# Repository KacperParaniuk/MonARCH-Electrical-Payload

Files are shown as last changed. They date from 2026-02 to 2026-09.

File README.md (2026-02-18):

# MonARCH Payload Interface Board

## Getting started

To make it easy for you to get started with GitLab, here's a list of recommended next steps.

Already a pro? Just edit this README.md and make it your own. Want to make it easy? [Use the template at the bottom](#editing-this-readme)!

## Add your files

- [ ] [Create](https://docs.gitlab.com/ee/user/project/repository/web_editor.html#create-a-file) or [upload](https://docs.gitlab.com/ee/user/project/repository/web_editor.html#upload-a-file) files
- [ ] [Add files using the command line](https://docs.gitlab.com/topics/git/add_files/#add-files-to-a-git-repository) or push an existing Git repository with the following command:

```
cd existing_repo
git remote add origin https://gitlab.engr.illinois.edu/cubesat/monarch-payload-interface-board.git
git branch -M main
git push -uf origin main
```

## Integrate with your tools

- [ ] [Set up project integrations](https://gitlab.engr.illinois.edu/cubesat/monarch-payload-interface-board/-/settings/integrations)

## Collaborate with your team

- [ ] [Invite team members and collaborators](https://docs.gitlab.com/ee/user/project/members/)
- [ ] [Create a new merge request](https://docs.gitlab.com/ee/user/project/merge_requests/creating_merge_requests.html)
- [ ] [Automatically close issues from merge requests](https://docs.gitlab.com/ee/user/project/issues/managing_issues.html#closing-issues-automatically)
- [ ] [Enable merge request approvals](https://docs.gitlab.com/ee/user/project/merge_requests/approvals/)
- [ ] [Set auto-merge](https://docs.gitlab.com/user/project/merge_requests/auto_merge/)

## Test and Deploy

Use the built-in continuous integration in GitLab.

- [ ] [Get started with GitLab CI/CD](https://docs.gitlab.com/ee/ci/quick_start/)
- [ ] [Analyze your code for known vulnerabilities with Static Application Security Testing (SAST)](https://docs.gitlab.com/ee/user/application_security/sast/)
- [ ] [Deploy to Kubernetes, Amazon EC2, or Amazon ECS using Auto Deploy](https://docs.gitlab.com/ee/topics/autodevops/requirements.html)
- [ ] [Use pull-based deployments for improved Kubernetes management](https://docs.gitlab.com/ee/user/clusters/agent/)
- [ ] [Set up protected environments](https://docs.gitlab.com/ee/ci/environments/protected_environments.html)

***

# Editing this README

When you're ready to make this README your own, just edit this file and use the handy template below (or feel free to structure it however you want - this is just a starting point!). Thanks to [makeareadme.com](https://www.makeareadme.com/) for this template.

## Suggestions for a good README

Every project is different, so consider which of these sections apply to yours. The sections used in the template are suggestions for most open source projects. Also keep in mind that while a README can be too long and detailed, too long is better than too short. If you think your README is too long, consider utilizing another form of documentation rather than cutting out information.

## Name
Choose a self-explaining name for your project.

## Description
Let people know what your project can do specifically. Provide context and add a link to any reference visitors might be unfamiliar with. A list of Features or a Background subsection can also be added here. If there are alternatives to your project, this is a good place to list differentiating factors.

## Badges
On some READMEs, you may see small images that convey metadata, such as whether or not all the tests are passing for the project. You can use Shields to add some to your README. Many services also have instructions for adding a badge.

## Visuals
Depending on what you are making, it can be a good idea to include screenshots or even a video (you'll frequently see GIFs rather than actual videos). Tools like ttygif can help, but check out Asciinema for a more sophisticated method.

## Installation
Within a particular ecosystem, there may be a common way of installing things, such as using Yarn, NuGet, or Homebrew. However, consider the possibility that whoever is reading your README is a novice and would like more guidance. Listing specific steps helps remove ambiguity and gets people to using your project as quickly as possible. If it only runs in a specific context like a particular programming language version or operating system or has dependencies that have to be installed manually, also add a Requirements subsection.

## Usage
Use examples liberally, and show the expected output if you can. It's helpful to have inline the smallest example of usage that you can demonstrate, while providing links to more sophisticated examples if they are too long to reasonably include in the README.

## Support
Tell people where they can go to for help. It can be any combination of an issue tracker, a chat room, an email address, etc.

## Roadmap
If you have ideas for releases in the future, it is a good idea to list them in the README.

## Contributing
State if you are open to contributions and what your requirements are for accepting them.

For people who want to make changes to your project, it's helpful to have some documentation on how to get started. Perhaps there is a script that they should run or some environment variables that they need to set. Make these steps explicit. These instructions could also be useful to your future self.

You can also document commands to lint the code or run tests. These steps help to ensure high code quality and reduce the likelihood that the changes inadvertently break something. Having instructions for running tests is especially helpful if it requires external setup, such as starting a Selenium server for testing in a browser.

## Authors and acknowledgment
Show your appreciation to those who have contributed to the project.

## License
For open source projects, say how it is licensed.

## Project status
If you have run out of energy or time for your project, put a note at the top of the README saying that development has slowed down or stopped completely. Someone may choose to fork your project or volunteer to step in as a maintainer or owner, allowing your project to keep going. You can also make an explicit request for maintainers.

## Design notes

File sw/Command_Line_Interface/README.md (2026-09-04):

# MonARCH Payload Interface Board Command Line Interface

*Created By Kacper Paraniuk 07-09-26 

[Dependency Info](#dependency-info)

[How to Set Up Dependencies](#how-to-set-up-dependencies--run-monarch-cli)

[1. UV INSTALLATION](#1-uv-installation-httpsdocsastralshuvgetting-startedinstallation)

[2. PYTHON](#2-python-httpsdocsastralshuvguidesinstall-python)

[3. RUNNING SCRIPT](#3-running-the-code)

[4. COMMANDING THE PIB](#4-commanding-the-pib)

[Common Errors](#common-errors)

## Dependency Info 

This markdown file discusses the structure of the payload interface shell (command line interface) and how to set it up 

uv — project + dependency management (replaces pip/venv juggling)

UV 

cmd module || read more here: https://docs.python.org/3/library/cmd.html

pyserial — external dependency for the serial side

cmd (Python stdlib, no install needed) — gives nice terminal commanding functionality  

## HOW TO SET UP DEPENDENCIES & RUN MonARCH CLI:

- type in terminal inside of project directory and run >

*If you do have UV installed:

uv sync (Make sure this is correct)

*If you do not have UV installed: 

### 1. UV INSTALLATION (https://docs.astral.sh/uv/getting-started/installation/)

WINDOWS - 

powershell -ExecutionPolicy ByPass -c "irm https://astral.sh/uv/install.ps1 | iex"

MAC - 

curl -LsSf https://astral.sh/uv/install.sh | sh

RESTART TERMINAL TO ADD UV TO PATH 

### 2. PYTHON (https://docs.astral.sh/uv/guides/install-python/)

If you do not have python no worries UV can manage your python type

uv python install

If you have python skip this step. 

### 3. RUNNING THE CODE

cd pib-cli # make sure you are in the pib-cli folder

uv run python main.py (port default = 12 | baud rate default = 115200) 

OR

uv run python main.py --port {Input COMX} --baud {Input Baud Rate}

Allows the user to specify the serial port and baud rate for the Arduino connection.

Windows: 

List COM ports with:

mode 

PS C:\dev\monarch-payload-interface-board\sw\Command_Line_Interface> mode

Status for device COM12:
------------------------
    Baud:            0
    Parity:          None
    Data Bits:       0
    Stop Bits:       1
    Timeout:         OFF
    XON/XOFF:        OFF
    CTS handshaking: OFF
    DSR handshaking: OFF
    DSR sensitivity: OFF
    DTR circuit:     OFF
    RTS circuit:     ON

Status for device CON:
----------------------
    Lines:          30
    Columns:        120
    Keyboard rate:  31
    Keyboard delay: 1
    Code page:      437

as you can see COM12 is active. 

then 

uv run python main.py --port COM12

MAC: 

List COM ports with 

ls /dev/cu.*

and the following should show up  
kacper@Kacpers-MacBook-Air-4 MonARCH-Payload-Control % ls /dev/cu.*
/dev/cu.BeatsFitPro             /dev/cu.debug-console           /dev/cu.usbmodem11101
/dev/cu.Bluetooth-Incoming-Port /dev/cu.HC-05                   /dev/cu.wlan-debug

then run the following command inside of pib-cli directory 

uv run python main.py --port /dev/cu.usbmodem11101

 1
### 4. Commanding the PIB!

If you sucessfully executed the program then you should see the following message:
    "Welcome to the PIB shell. Use with an arduino to command the payload interface board of MonARCH. Type help or ? to list commands."

Now you can start running various commands.

See the command .md [Commanding the PIB](https://github.com/KacperParaniuk/MonARCH-Payload-Control/blob/main/Command_Line_Interface/cmds.md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)

# Common Errors: 

 >   raise SerialException(msg.errno, "could not open port {}: {}".format(self._port, msg))

This is due to the python script failing a handshake with the arduino board. Please check the connection between computer and arduino board. Also check if you are specifiying the correct port the device is identified at.

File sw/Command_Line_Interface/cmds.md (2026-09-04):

Created By Kacper Paraniuk 07-06-26 

This is a markdown file containing the commands for cli of the payload interface board 

[Command Structure](#command-structure)

[Commands Explanation](#commands-explanation)

[Commands](#commands)

# Command Structure

The command structure is:

 <verb> <target> 

# Commands Explanation: 

Sensors 
-----------------------------------------------------------------------------------------------------------

<verb> <target> <[num]>

ex: 

read_cj_temp 1 

read_pressure 2

read_temp 5

Actions 
-----------------------------------------------------------------------------------------------------------
<verb> <target> <[num]>

ex: 

open_valve 3

toggle_red_led

Events -----------------------------------------------------------------------------------------------------------

<verb> <event>

ex: 

run_sequence fill_accum1

run_sequence run_espray 

# PIB Shell Commands

| Command | Usage | Description |
|---|---|---|
| `greet` | `greet <text>` | Echoes back `Hello <text>` |
| `exit` | `exit` | Echoes `Exiting the PIB shell.` and exits the script |
| `help` | `help` | Returns a list of commands
| `toggle_red_led` | `toggle_red_led` | Toggles the red debug LED on the PIB |
| `open_valve` | `open_valve <valve #>` | Opens the specified valve |
| `close_valve` | `close_valve <valve #>` | Closes the specified valve |
| `read_cj_temp` | `read_cj_temp <sensor #>` | Returns the cold junction temperature |
| `

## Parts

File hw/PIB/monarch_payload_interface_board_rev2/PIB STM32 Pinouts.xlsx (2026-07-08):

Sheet: Pinout Descriptions
Model | STM32L4A6VGT6 |  |  |  |  | Legend
Package | 100 - LQFP |  |  |  |  | Name | Abbreviation | Definition
 |  |  |  |  |  | Pin name | Unless otherwise specified in brackets below the pin name, the pin function during and after reset is the same as the actual pin name
 |  |  |  |  |  | Pin type | S | Supply pin
Pin Number | Pin Name | Pin Type | I/O Structure | Function | Description |  | I | Input only pin
1 | PE2 | I/O | FT_l | GPIO | Chip Select for Thermocouple 4 |  | I/O | Input / output pin
2 | PE3 | I/O | FT_l | GPIO | Chip Select for Thermocouple 2 | I/O structure | FT | 5 V tolerant I/O
3 | PE4 | I/O | FT | GPIO | Chip Select for Pressure Transducer ADC |  | TT | 3.6 V tolerant I/O
4 | PE5 | I/O | FT | TIM3_CH3 | Advanced Clock for Controlling Valve6 |  | RST | Bidirectional reset pin with embedded weak pull-up resistor
5 | PE6 | I/O | FT | N/A | Not Connected |  | Option for TT or FT I/Os
6 | VBAT | S | - | N/A | Not Connected |  | _f | I/O, Fm+ capable
7 | PC13 | I/O | FT | N/A | Not Connected |  | _l | I/O, with LCD function supplied by VLCD
8 | PC14 | I/O | FT | N/A | Not Connected |  | _u | I/O, with USB function supplied by VDDUSB
9 | PC15 | I/O | FT | N/A | Not Connected |  | _a | I/O, with Analog switch function supplied by VDDA
10 | VSS | S | - | GND | Ground Pin |  | _s | I/O supplied only by VDDIO2
11 | VDD | S | - | 3V3 | 3V3 Supply Pin | Color Coding |  | Pin Not Connected
12 | PH0 | I/O | FT | GPIO | Enable Pin for DC/DC Converter |  |  | GPIO for Controlling Valves / Chip Selects
13 | PH1 | I/O | FT | N/A | Not Connected |  |  | Ground Pins
14 | NRST | I/O | RST | RST | Reset Pin |  |  | 3V3 Supply Pins
15 | PC0 | I/O | FT_fla | N/A | Not Connected |  |  | Reset Pin
16 | PC1 | I/O | FT_fla | N/A | Not Connected |  |  | Communication Protocols
17 | PC2 | I/O | FT_la | N/A | Not Connected |  |  | Advanced Timers for Valves 4 & 6
18 | PC3 | I/O | FT_la | N/A | Not Connected |  |  | STLink Pins for Programming Pin Headers
19 | VSSA | S | - | GND | Analog Ground Pin (Same as GND)
20 | VREF- | S | - | GND | Reference Ground Pin (Same as GND)
21 | VREF+ | S | - | 3V3 | Reference Voltage Pin (Same as 3V3)
22 | VDDA | S | - | 3V3 | Analog Voltage Pin (Same as 3V3)
23 | PA0 | I/O | FT_a | UART4_TX | UART Protocol for PPU Communication
24 | PA1 | I/O | FT_la | UART4_RX | UART Protocol for PPU Communication
25 | PA2 | I/O | FT_la | N/A | Not Connected
26 | PA3 | I/O | TT_la | N/A | Not Connected
27 | VSS | S | - | GND | Ground Pin
28 | VDD | S | - | 3V3 | 3V3 Supply Pin
29 | PA4 | I/O | TT_a | GPIO | Chip Select for Current Measurement ADC
30 | PA5 | I/O | TT_a | SPI1_SCK | SPI Clock for ADC
31 | PA6 | I/O | FT_la | SPI1_MISO | SPI MISO for ADC
32 | PA7 | I/O | FT_fla | SPI1_MOSI | SPI MOSI for ADC
33 | PC4 | I/O | FT_la | USART3_TX | USART Protocol for OBC Communication
34 | PC5 | I/O | FT_la | USART3_RX | USART Protocol for OBC Communication
35 | PB0 | I/O | TT_la | N/A | Not Connected
36 | PB1 | I/O | FT_la | N/A | Not Connected
37 | PB2 | I/O | FT_la | N/A | Not Connected
38 | PE7 | I/O | FT | N/A | Not Connected
39 | PE8 | I/O | FT | N/A | Not Connected
40 | PE9 | I/O | FT | N/A | Not Connected
41 | PE10 | I/O | FT | N/A | Not Connected
42 | PE11 | I/O | FT | N/A | Not Connected
43 | PE12 | I/O | FT | N/A | Not Connected
44 | PE13 | I/O | FT | GPIO | GPIO for Test LED (BLUE)
45 | PE14 | I/O | FT | GPIO | GPIO for Test LED (GREEN)
46 | PE15 | I/O | FT | GPIO | GPIO for Test LED (RED)
47 | PB10 | I/O | FT_fl | I2C4_SCL | I2C Protocol for Breakout Board Communication
48 | PB11 | I/O | FT_fl | I2C4_SDA | I2C Protocol for Breakout Board Communication
49 | VSS | S | - | GND | Ground Pin
50 | VDD | S | - | 3V3 | 3V3 Supply Pin
51 | PB12 | I/O | FT_l | GPIO | GPIO for Valve1
52 | PB13 | I/O | FT_fl | GPIO | GPIO for Valve2
53 | PB14 | I/O | FT_fl | GPIO | GPIO for Valve3
54 | PB15 | I/O | FT_l | GPIO | GPIO for Valve5
55 | PD8 | I/O | FT_l | GPIO | GPIO for Valve7
56 | PD9 | I/O | FT_l | GPIO | GPIO for Valve8
57 | PD10 | I/O | FT_l | N/A | Not Connected
58 | PD11 | I/O | FT_l | N/A | Not Connected
59 | PD12 | I/O | FT_fl | N/A | Not Connected
60 | PD13 | I/O | FT_fl | N/A | Not Connected
61 | PD14 | I/O | FT_l | N/A | Not Connected
62 | PD15 | I/O | FT_l | N/A | Not Connected
63 | PC6 | I/O | FT_l | TIM8_CH1 | Advanced Clock for Controlling Valve4
64 | PC7 | I/O | FT_l | GPIO | GPIO for Valve9
65 | PC8 | I/O | FT_l | GPIO | GPIO for Valve10
66 | PC9 | I/O | FT_fl | GPIO | GPIO for Valve11
67 | PA8 | I/O | FT_l | GPIO | GPIO for Valve12
68 | PA9 | I/O | FT_lu | N/A | Not Connected
69 | PA10 | I/O | FT_lu | GPIO | GPIO for Heater0
70 | PA11 | I/O | FT_u | GPIO | GPIO for Valve18
71 | PA12 | I/O | FT_u | N/A | Not Connected
72 | PA13 (JTMS / SWDIO) | I/O | FT | JTMS | JTMS for STLink Programming
73 | VDDUSB | S | - | N/A | Not Connected
74 | VSS | S | - | GND | Ground Pin
75 | VDD | S | - | 3V3 | 3V3 Supply Pin
76 | PA14 (JTCK / SWCLK) | I/O | FT | JTCK | JTCK for STLink Programming
77 | PA15 (JTDI) | I/O | FT_l | JTDI | JTDI for STLink Programming
78 | PC10 | I/O | FT_l | GPIO | GPIO for Value13
79 | PC11 | I/O | FT_l | GPIO | GPIO for Valve14
80 | PC12 | I/O | FT_l | GPIO | GPIO for Valve16
81 | PD0 | I/O | FT | GPIO | GPIO for Valve17
82 | PD1 | I/O | FT | SPI2_SCK | SPI_SCK for Thermocouple Chips
83 | PD2 | I/O | FT_l | GPIO | GPIO for Valve15
84 | PD3 | I/O | FT | SPI2_MISO | SPI_MISO for Thermocouple Chips
85 | PD4 | I/O | FT | SPI2_MOSI | SPI_MOSI for Termocouple Chips
86 | PD5 | I/O | FT | N/A | Not Connected
87 | PD6 | I/O | FT | N/A | Not Connected
88 | PD7 | I/O | FT | N/A | Not Connected
89 | PB3 (JTDO / TRACES WO) | I/O | FT_la | JTDO | JTDO for STLink Programming
90 | PB4 (NJTRST) | I/O | FT_fla | NJTRST | NJTRST for STLink Programming
91 | PB5 | I/O | FT_la | N/A | Not Connected
92 | PB6 | I/O | FT_fa | N/A | Not Connected
93 | PB7 | I/O | FT_fla | N/A | Not Connected
94 | PH3-BOOT0 | I/O | FT | N/A | Not Connected
95 | PB8 | I/O | FT_fl | N/A | Not Connected
96 | PB9 | I/O | FT_fl | GPIO | Chip Select for Thermocouple 1
97 | PE0 | I/O | FT_l | GPIO | Chip Select for Thermocouple 3
98 | PE1 | I/O | FT_l | GPIO | Chip Select for Thermocouple 5
99 | VSS | S | - | GND | Ground Pin
100 | VDD | S | - | 3V3 | 3V3 Supply Pin

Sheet: STM Model
 |  | 25 | 24 | 23 | 22 | 21 | 20 | 19 | 18 | 17 | 16 | 15 | 14 | 13 | 12 | 11 | 10 | 9 | 8 | 7 | 6 | 5 | 4 | 3 | 2 | 1
 |  | NC | UART4_TX | UART4_RX | 3V3 | 3V3 | GND | GND | NC | NC | NC | NC | NRST | NC | EN | 3V3 | GND | NC | NC | NC | NC | NC | NC | PT | T2 | T4
26 | NC | STM32 |  |  |  |  |  |  |  |  |  |  |  |  |  |  |  |  |  |  |  |  |  |  |  |  | 3V3 | 100
27 | GND |  |  |  |  |  |  |  |  |  |  |  |  |  |  |  |  |  |  |  |  |  |  |  |  |  | GND | 99
28 | 3V3 |  |  |  |  |  |  |  |  |  |  |  |  |  |  |  |  |  |  |  |  |  |  |  |  |  | T5 | 98
29 | ADC |  |  |  |  |  |  |  |  |  |  |  |  |  |  |  |  |  |  |  |  |  |  |  |  |  | T3 | 97
30 | SPI1_SCK |  |  |  |  |  |  |  |  |  |  |  |  |  |  |  |  |  |  |  |  |  |  |  |  |  | T1 | 96
31 | SPI1_MISO |  |  |  |  |  |  |  |  |  |  |  |  |  |  |  |  |  |  |  |  |  |  |  |  |  | NC | 95
32 | SPI1_MOSI |  |  |  |  |  |  |  |  |  |  |  |  |  |  |  |  |  |  |  |  |  |  |  |  |  | NC | 94
33 | USART3_TX |  |  |  |  |  |  |  |  |  |  |  |  |  |  |  |  |  |  |  |  |  |  |  |  |  | NC | 93
34 | USART3_RX |  |  |  |  |  |  |  |  |  |  |  |  |  |  |  |  |  |  |  |  |  |  |  |  |  | NC | 92
35 | NC |  |  |  |  |  |  |  |  |  |  |  |  |  |  |  |  |  |  |  |  |  |  |  |  |  | NC | 91
36 | NC |  |  |  |  |  |  |  |  |  |  |  |  |  |  |  |  |  |  |  |  |  |  |  |  |  | NJTRST | 90
37 | NC |  |  |  |  |  |  |  |  |  |  |  |  |  |  |  |  |  |  |  |  |  |  |  |  |  | JTDO | 89
38 | NC |  |  |  |  |  |  |  |  |  |  |  |  |  |  |  |  |  |  |  |  |  |  |  |  |  | NC | 88
39 | NC |  |  |  |  |  |  |  |  |  |  |  |  |  |  |  |  |  |  |  |  |  |  |  |  |  | NC | 87
40 | Valve6 |  |  |  |  |  |  |  |  |  |  |  |  |  |  |  |  |  |  |  |  |  |  |  |  |  | NC | 86
41 | NC |  |  |  |  |  |  |  |  |  |  |  |  |  |  |  |  |  |  |  |  |  |  |  |  |  | SPI2_MOSI | 85
42 | NC |  |  |  |  |  |  |  |  |  |  |  |  |  |  |  |  |  |  |  |  |  |  |  |  |  | SPI2_MISO | 84
43 | NC |  |  |  |  |  |  |  |  |  |  |  |  |  |  |  |  |  |  |  |  |  |  |  |  |  | Valve15 | 83
44 | NC |  |  |  |  |  |  |  |  |  |  |  |  |  |  |  |  |  |  |  |  |  |  |  |  |  | SPI2_SCK | 82
45 | NC |  |  |  |  |  |  |  |  |  |  |  |  |  |  |  |  |  |  |  |  |  |  |  |  |  | Valve17 | 81
46 | LED |  |  |  |  |  |  |  |  |  |  |  |  |  |  |  |  |  |  |  |  |  |  |  |  |  | Valve16 | 80
47 | I2C4_SCL |  |  |  |  |  |  |  |  |  |  |  |  |  |  |  |  |  |  |  |  |  |  |  |  |  | Valve14 | 79
48 | I2C4_SDA |  |  |  |  |  |  |  |  |  |  |  |  |  |  |  |  |  |  |  |  |  |  |  |  |  | Valve13 | 78
49 | GND |  |  |  |  |  |  |  |  |  |  |  |  |  |  |  |  |  |  |  |  |  |  |  |  |  | JTDI | 77
50 | 3V3 |  |  |  |  |  |  |  |  |  |  |  |  |  |  |  |  |  |  |  |  |  |  |  |  |  | JTCK | 76
 |  | Valve1 | Valve2 | Valve3 | Valve5 | Valve7 | Valve8 | NC | NC | NC | NC | NC | NC | Valve4 | Valve9 | Valve10 | Valve11 | Valve12 | NC | Heater0 | Valve18 | NC | JTMS | NC | GND | 3V3
 |  | 51 | 52 | 53 | 54 | 55 | 56 | 57 | 58 | 59 | 60 | 61 | 62 | 63 | 64 | 65 | 66 | 67 | 68 | 69 | 70 | 71 | 72 | 73 | 74 | 75

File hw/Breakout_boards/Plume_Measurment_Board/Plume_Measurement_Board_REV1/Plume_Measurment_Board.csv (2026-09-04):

Reference | Qty | Value | DNP | Exclude from BOM | Exclude from Board | Footprint | Datasheet
C1 | 1 | 620pF |  |  |  | Capacitor_SMD:C_0402_1005Metric_Pad0.74x0.62mm_HandSolder | https://www.digikey.com/en/products/detail/murata-electronics/GRM1555C1E621JA01D/2543753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
C2,C12,C14,C32,C42 | 5 | 10uF |  |  |  | Capacitor_SMD:C_0805_2012Metric_Pad1.18x1.45mm_HandSolder | https://www.digikey.com/en/products/detail/nextgen-components/0805W106K250CC/18676983
C3 | 1 | 22uF |  |  |  | Capacitor_SMD:C_0805_2012Metric_Pad1.18x1.45mm_HandSolder | https://www.digikey.com/en/products/detail/nextgen-components/0805W226M100CC/22671955
C4,C31 | 2 | .1uF |  |  |  | Capacitor_SMD:C_0603_1608Metric_Pad1.08x0.95mm_HandSolder
C5,C6,C9,C10,C38,C39,C40,C41 | 8 | 270pF |  |  |  | Capacitor_SMD:C_0603_1608Metric_Pad1.08x0.95mm_HandSolder
C7,C8,C35,C36 | 4 | 680pF |  |  |  | Capacitor_SMD:C_0603_1608Metric_Pad1.08x0.95mm_HandSolder
C11,C19,C20,C22,C25,C27,C29,C34 | 8 | 1uF |  |  |  | Capacitor_SMD:C_0603_1608Metric_Pad1.08x0.95mm_HandSolder
C13,C15,C33,C43 | 4 | 100nF |  |  |  | Capacitor_SMD:C_0603_1608Metric_Pad1.08x0.95mm_HandSolder
C16,C18,C21,C23,C26,C28,C30,C37 | 8 | 1uF |  |  |  | Capacitor_SMD:C_0805_2012Metric_Pad1.18x1.45mm_HandSolder
C17,C24 | 2 | .1pF |  |  |  | Capacitor_SMD:C_0402_1005Metric_Pad0.74x0.62mm_HandSolder | https://www.digikey.com/en/products/detail/murata-electronics/GJM1555C1HR10WB01D/2593239
J2,J4 | 2 | Conn_01x04 |  |  |  | Connector_Molex_Micro-Lock-Plus:Molex_Micro-Lock_2200980471_1x04_P1.25mm_Horizontal
J3,J5 | 2 | Conn_Coaxial |  |  |  | Connector_Coaxial:SMA_Molex_73251-2120_EdgeMount_Horizontal | https://www.digikey.com/en/products/detail/molex/0732512120/1465158?s=N4IgTCBcDaIAQHYDMYCsBGAtGdYAMcIAugL5A
L1 | 1 | 2.2uH |  |  |  | Inductor_TDK:IND_VLS3012CX-2R2M-1 | https://www.digikey.com/en/products/detail/tdk/VLS3012CX-2R2M-1/9607846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
R1 | 1 | 100k |  |  |  | Resistor_SMD:R_01005_0402Metric_Pad0.57x0.30mm_HandSolder | https://www.digikey.com/en/products/detail/vishay-dale/CRCW0402100KFKED/1178235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
R3,R4,R5,R6,R7,R8,R19,R20 | 8 | 10 |  |  |  | Resistor_SMD:R_0603_1608Metric_Pad0.98x0.95mm_HandSolder
R9,R10,R17,R18 | 4 | 1000 |  |  |  | Resistor_SMD:R_0603_1608Metric_Pad0.98x0.95mm_HandSolder
R11,R12,R15,R16 | 4 | 1000 | DNP |  |  | Resistor_SMD:R_0603_1608Metric_Pad0.98x0.95mm_HandSolder
R13,R14 | 2 | 1G |  |  |  | Resistor_SMD:R_2512_6332Metric_Pad1.40x3.35mm_HandSolder | https://www.digikey.com/en/products/detail/stackpole-electronics-inc/HVCB2512FKC1G00/1948075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
U2,U10 | 2 | LMP7721MA/NOPB |  |  |  | Amplifier_Texas_Instruments:M08A | https://www.ti.com/lit/gpn/lmp7721
U3,U11 | 2 | LMP2022MA/NOPB |  |  |  | Amplifier_Texas_Instruments:M08A | https://www.ti.com/lit/gpn/lmp2022
U4,U5,U8,U9 | 4 | AD8475ARMZ |  |  |  | Buffer_Analog_Devices:RM_10_ADI | https://www.analog.com/media/en/technical-documentation/data-sheets/AD8475.pdf
U6 | 1 | TPS62153 |  |  |  | Package_DFN_QFN:VQFN-16-1EP_3x3mm_P0.5mm_EP1.68x1.68mm_ThermalVias | http://www.ti.com/lit/ds/symlink/TPS62150.pdf
U7,U12 | 2 | AD7176-2BRUZ |  |  |  | ADC_Analog_Devices:RU_24_ADI | https://www.analog.com/media/en/technical-documentation/data-sheets/AD7176-2.pdf

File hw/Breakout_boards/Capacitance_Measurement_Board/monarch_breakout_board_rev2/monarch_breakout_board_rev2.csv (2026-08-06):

Reference | Qty | Value | DNP | Exclude from BOM | Exclude from Board | Footprint | Datasheet
U1 | 1 | FDC2214RGHR |  |  |  | FDC2214:RGH0016A | https://www.ti.com/lit/gpn/fdc2214
J9 | 1 | 2200980471 |  |  |  | Connector_Molex_Micro-Lock-Plus:Molex_Micro-Lock_2200980471_1x04_P1.25mm_Horizontal | https://www.molex.com/en-us/products/part-detail/2200980471
R1 | 1 | 100 |  |  |  | Resistor_SMD:R_0603_1608Metric_Pad0.98x0.95mm_HandSolder | https://www.digikey.com/en/products/detail/yageo/RC0603FR-07100RL/726888
D1 | 1 | RED LED |  |  |  | LED_SMD:LED_0603_1608Metric_Pad1.05x0.95mm_HandSolder | https://www.digikey.com/en/products/detail/w%C3%BCrth-elektronik/150060RS55040/8557180
C22 | 1 | 0.1 uF |  |  |  | Capacitor_SMD:C_0603_1608Metric | https://www.digikey.com/en/products/detail/tdk-corporation/C1608X5R1H104M080AA/2732892
C21 | 1 | 1uF |  |  |  | Capacitor_SMD:C_0603_1608Metric | https://www.digikey.com/en/products/detail/tdk-corporation/C1608JB1H105M080AB/3948500
C5,C6,C7,C8,C9,C10,C11,C12,C13,C14,C15,C16,C17,C18,C19,C20 | 16 | 18pF |  |  |  | Capacitor_SMD:C_0603_1608Metric | https://www.digikey.com/en/products/detail/murata-electronics/GRM1885C2A180JA01D/586990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
C1,C2,C3,C4 | 4 | 33pF |  |  |  | Capacitor_SMD:C_0603_1608Metric | https://www.digikey.com/en/products/detail/murata-electronics/GJM0335C1E330GB01D/11618733
L1,L2,L3,L4 | 4 | 18uH |  |  |  | Inductor_Bourns:INDM3225X240N | https://www.digikey.com/en/products/detail/bourns-inc/CM322522-180KL/3741386
TP1,TP2,TP3,TP4 | 4 | TestPoint |  |  |  | TestPoint:TestPoint_Keystone_5000-5004_Miniature
J1,J2,J3,J4 | 4 | Conn_01x02 |  |  |  | Connector_Molex_Micro-Lock-Plus:Molex_Micro-Lock_2200980271_1x02_P1.25mm_Horizontal

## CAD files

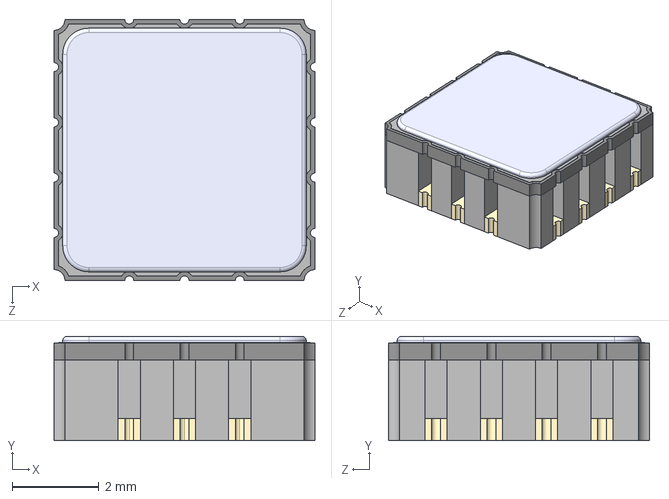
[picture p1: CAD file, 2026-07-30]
hw/Breakout_boards/Capacitance_Measurement_Board/monarch_breakout_board_rev2/ADXL355BEZ/ADXL355BEZ.step
6.00 x 2.40 x 6.00 mm

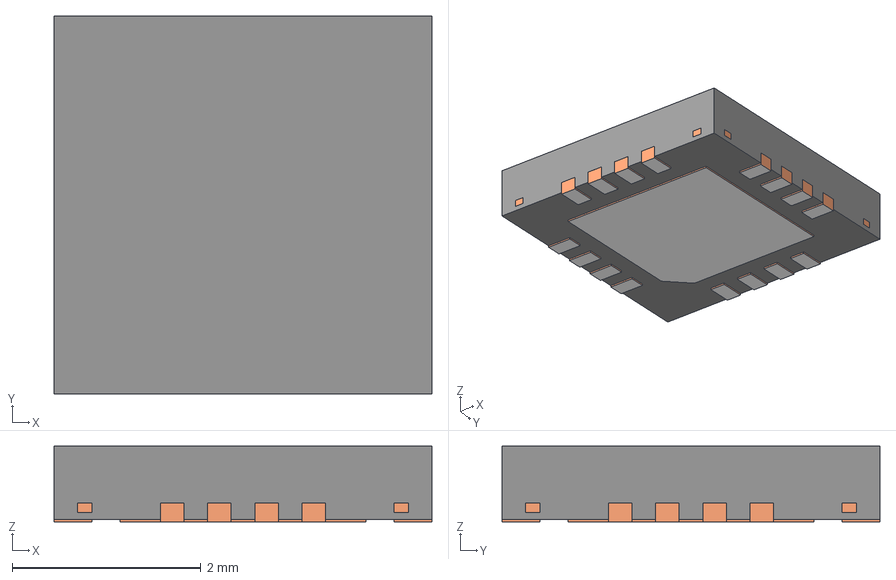
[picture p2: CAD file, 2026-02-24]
hw/Breakout_boards/Capacitance_Measurement_Board/monarch_breakout_board_rev2/FDC2214/RGH0016A.stp
4.00 x 4.00 x 0.8 mm
BODY-QFN
FRAME-RGH0016A
PIN1-ID

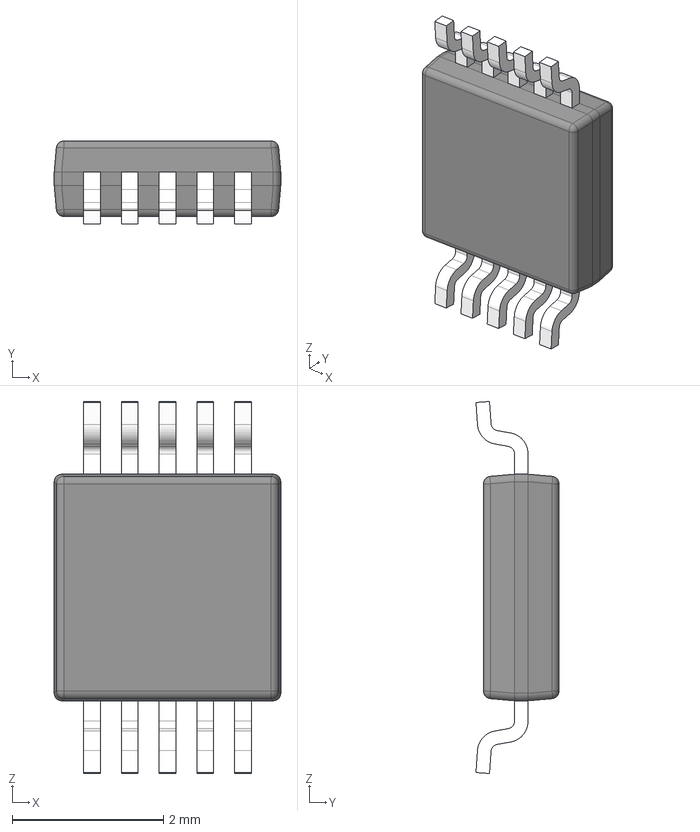
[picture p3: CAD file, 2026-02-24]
hw/Breakout_boards/Capacitance_Measurement_Board/monarch_breakout_board_rev2/INA226-Q1/DGS0010A.stp
3.00 x 1.10 x 4.93 mm
BODY-SO
LEAD-SO x 10
PIN1-ID

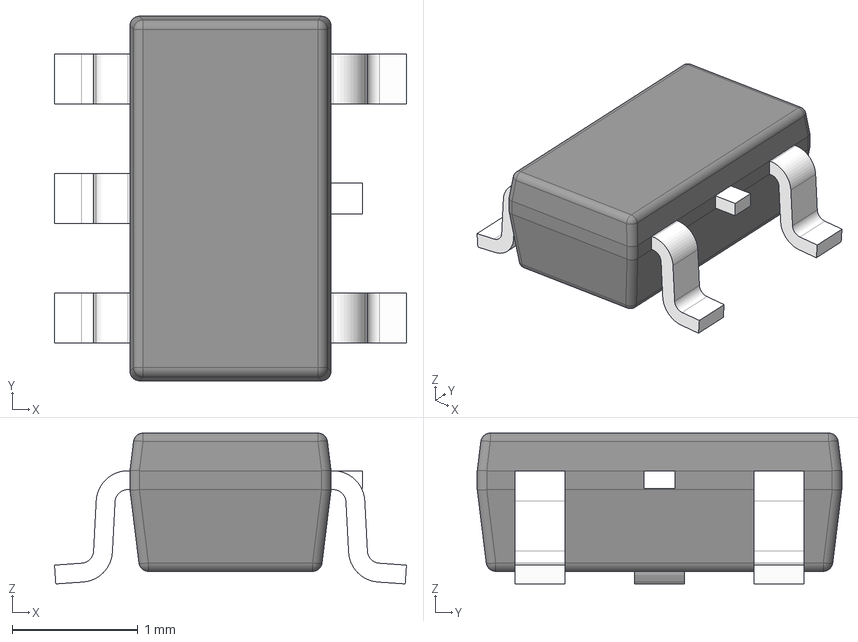
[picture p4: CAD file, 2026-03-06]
hw/Breakout_boards/Capacitance_Measurement_Board/monarch_breakout_board_rev2/OPA320/DBV0005A.stp
2.80 x 2.90 x 1.20 mm
BODY-SOT
LEAD-SOT x 5
LEAD-DUMMY

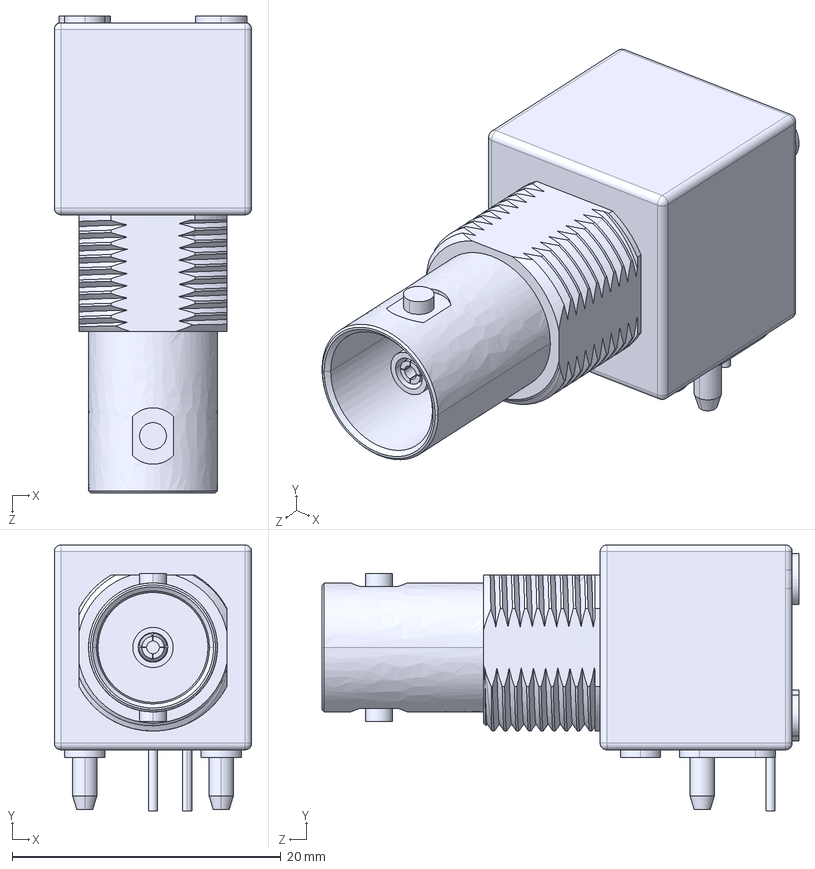
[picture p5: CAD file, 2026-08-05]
hw/Breakout_boards/Capacitance_Measurement_Board/monarch_breakout_board_rev2/RF1-01A-D-00-75-M/3D/RF1-01A-D-00-75-M.stp
14.7 x 19.8 x 35.5 mm

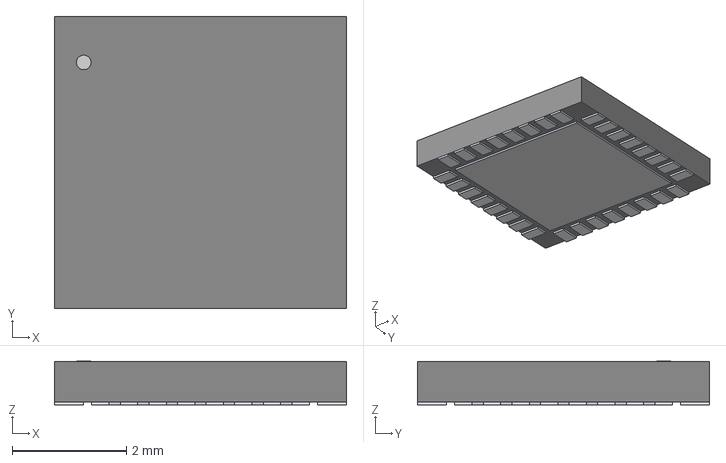
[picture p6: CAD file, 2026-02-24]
hw/Breakout_boards/Plume_Measurment_Board/Plume_Measurement_Board_REV1/AD7124_8BCPZ_RL/CP-32-12_ADI.step
5.11 x 5.11 x 0.765 mm

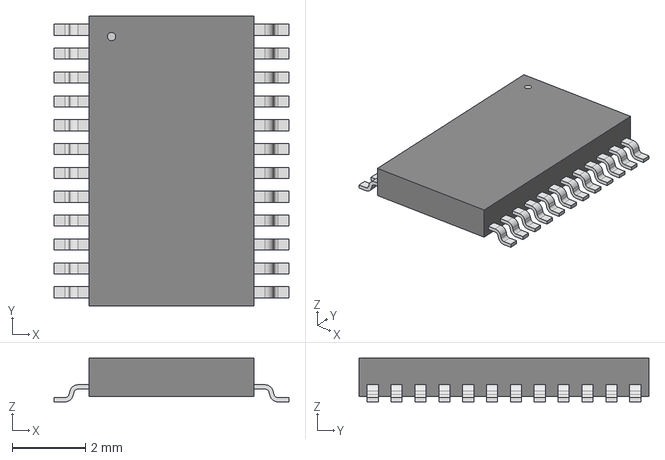
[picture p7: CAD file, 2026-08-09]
hw/Breakout_boards/Plume_Measurment_Board/Plume_Measurement_Board_REV1/AD7176_2BRUZ/RU_24_ADI.step
6.40 x 7.90 x 1.20 mm

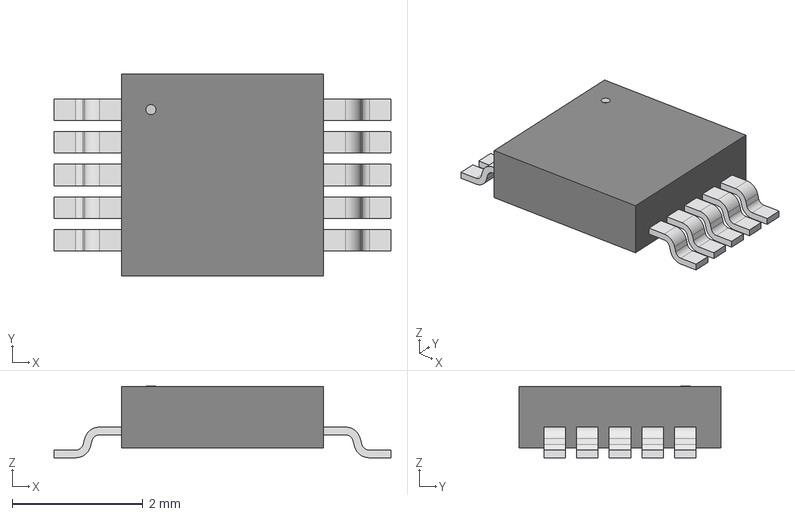
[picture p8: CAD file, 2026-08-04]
hw/Breakout_boards/Plume_Measurment_Board/Plume_Measurement_Board_REV1/AD8475ARMZ/RM_10_ADI.step
5.16 x 3.10 x 1.09 mm

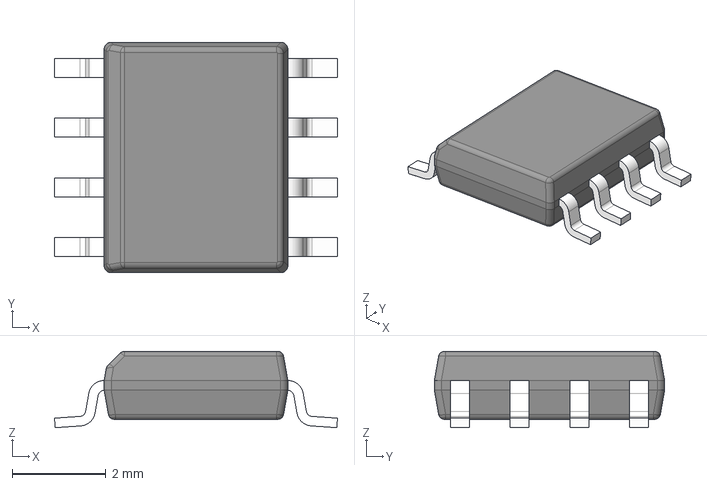
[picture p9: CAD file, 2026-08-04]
hw/Breakout_boards/Plume_Measurment_Board/Plume_Measurement_Board_REV1/LMP2022MA_NOPB/D0008A.stp
6.02 x 4.90 x 1.63 mm
BODY-SO
LEAD-D0008A x 8

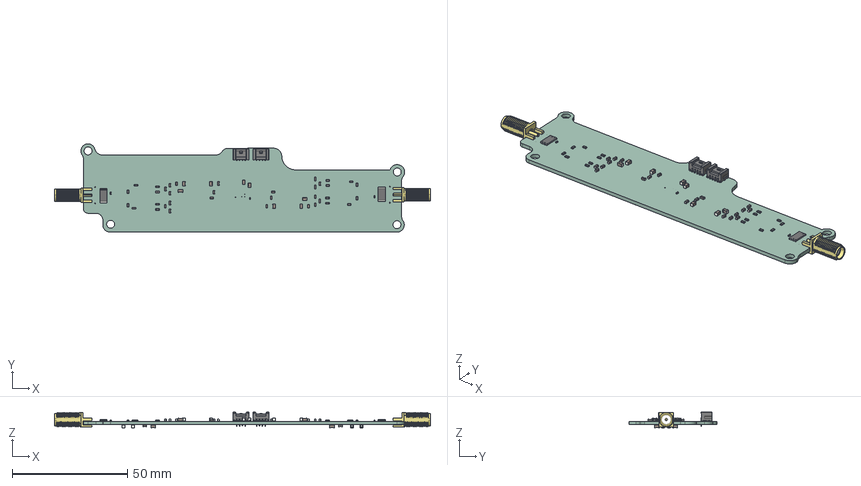
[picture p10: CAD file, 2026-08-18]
hw/Breakout_boards/Plume_Measurment_Board/Plume_Measurement_Board_REV1/Plume_Measurement_Board_Mounting_Holes.step
162.9 x 38.3 x 6.78 mm
C_0805_2012Metric x 14
R_2512_6332Metric x 2
C_0603_1608Metric x 26
R_0603_1608Metric x 16
R_01005_0402Metric
C_0402_1005Metric x 3
Plume_Measurment_Board_PCB

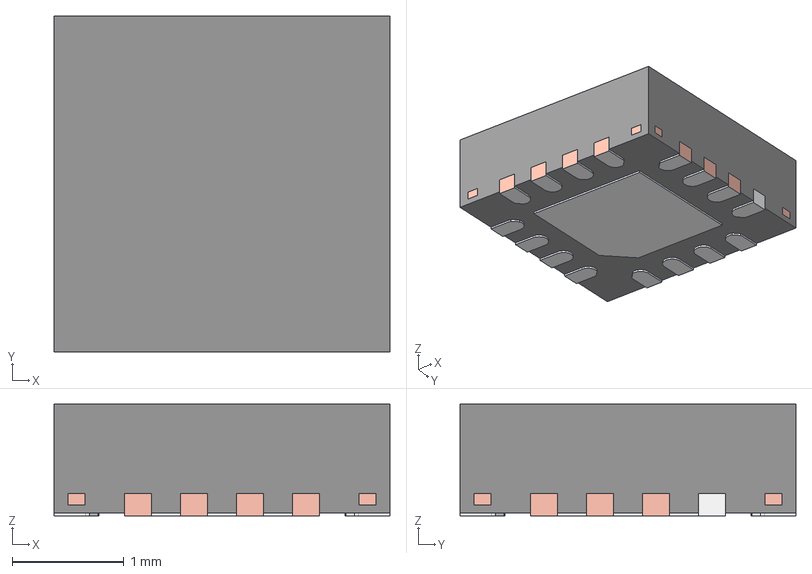
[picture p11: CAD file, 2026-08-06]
hw/Breakout_boards/Plume_Measurment_Board/Plume_Measurement_Board_REV1/TPS62153RGTR/RGT0016C.stp
3.00 x 3.00 x 1.00 mm
BODY-QFN
FRAME-RGT0016C
PIN1-ID

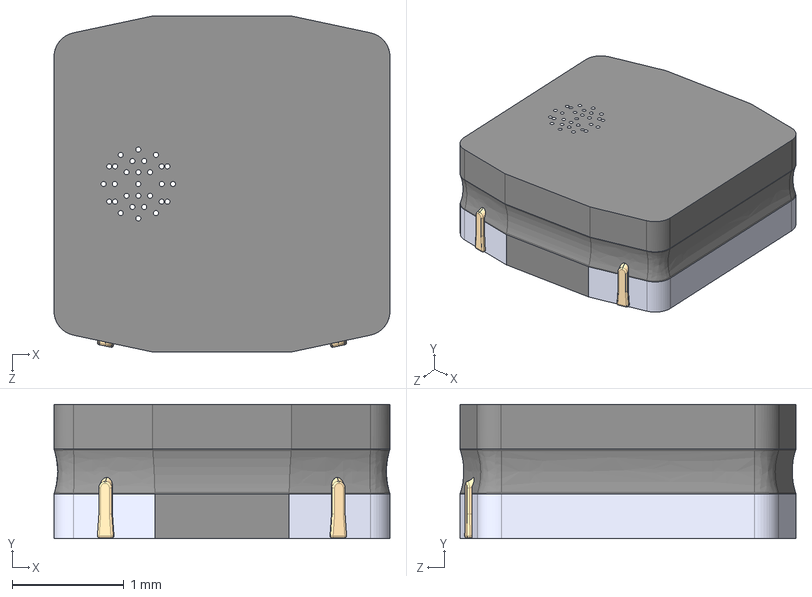
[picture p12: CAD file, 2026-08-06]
hw/Breakout_boards/Plume_Measurment_Board/Plume_Measurement_Board_REV1/VLS3012CX-2R2M-1/VLS3012CX-2R2M-1.step
3.00 x 1.20 x 3.00 mm

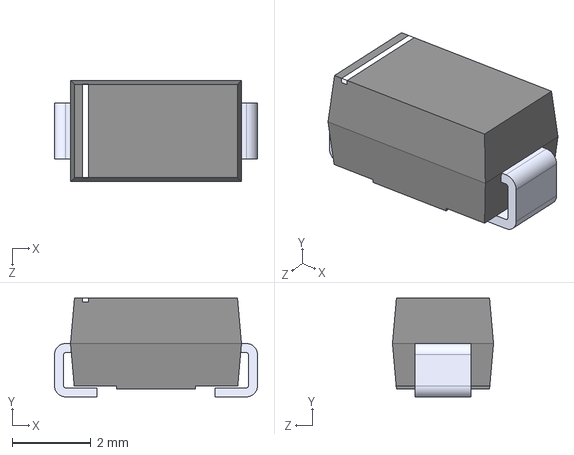
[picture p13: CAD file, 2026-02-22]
hw/PIB/monarch_payload_interface_board_rev2/1SMA4757/1SMA4757.step
5.14 x 2.50 x 2.56 mm

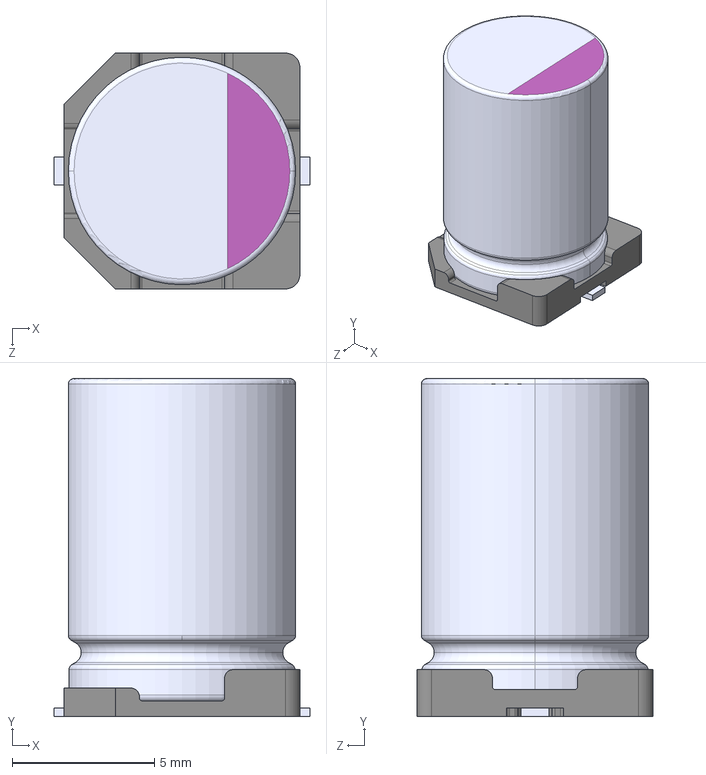
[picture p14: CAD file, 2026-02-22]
hw/PIB/monarch_payload_interface_board_rev2/35SVT82M/35SVT82M.step
9.00 x 11.9 x 8.30 mm

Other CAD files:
hw/PIB/monarch_payload_interface_board_rev2/EXLA1V0402-R82-R/EXLA.stp
hw/PIB/monarch_payload_interface_board_rev2/LIB_FZT600TA/FZT600TA/3D/FZT600TA.stp
hw/PIB/monarch_payload_interface_board_rev2/NZT7053/SOT-223_ONS.step
hw/PIB/monarch_payload_interface_board_rev2/PIB_REV2.step
hw/Breakout_boards/Capacitance_Measurement_Board/monarch_breakout_board_rev1/5037630291/5037630291.stp
hw/Breakout_boards/Capacitance_Measurement_Board/monarch_breakout_board_rev1/5037630491/5037630491.stp
hw/Breakout_boards/Capacitance_Measurement_Board/monarch_breakout_board_rev1/breakout_board_rev1.step
hw/Breakout_boards/Capacitance_Measurement_Board/monarch_breakout_board_rev2/5037630291/5037630291.stp
hw/Breakout_boards/Capacitance_Measurement_Board/monarch_breakout_board_rev2/5037630491/5037630491.stp
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

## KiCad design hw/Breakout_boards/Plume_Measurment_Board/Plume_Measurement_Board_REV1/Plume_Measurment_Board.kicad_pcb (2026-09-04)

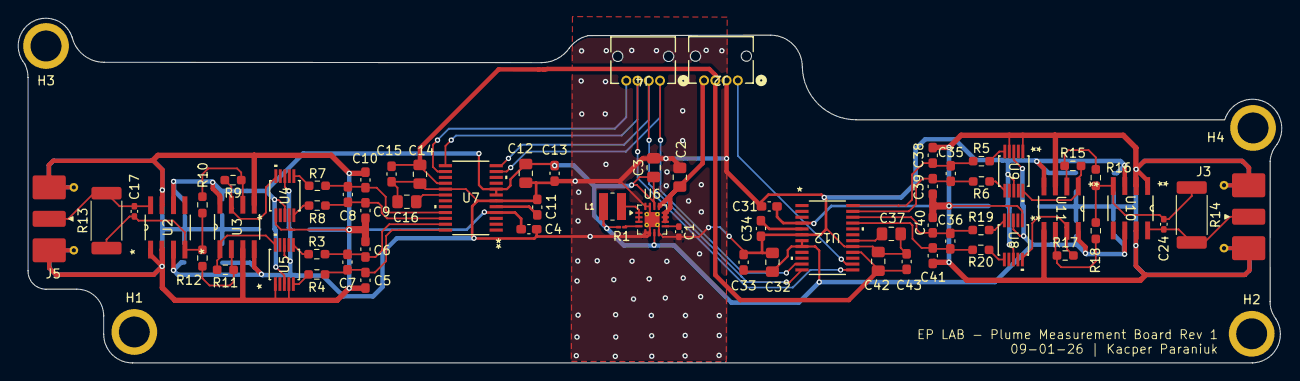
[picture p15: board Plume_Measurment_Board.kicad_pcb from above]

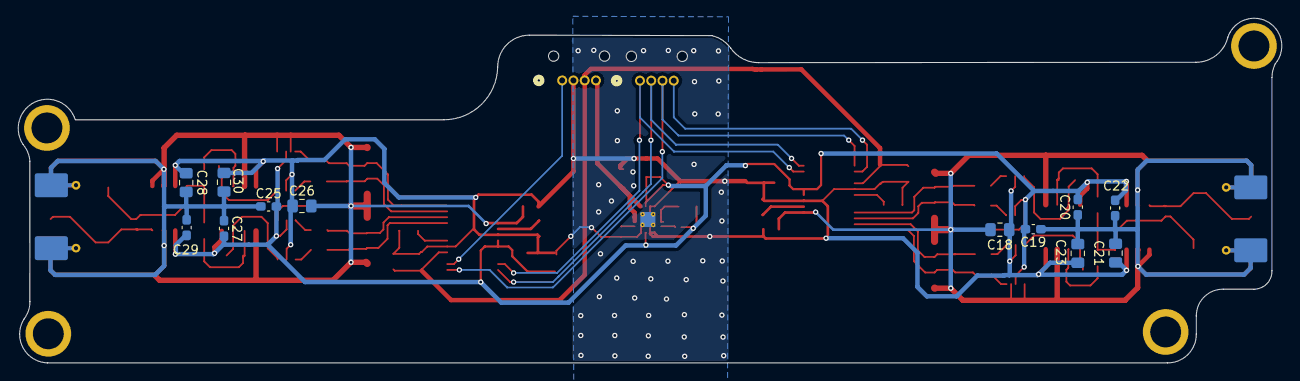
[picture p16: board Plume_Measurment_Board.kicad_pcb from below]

Board: 2 copper layers, 140.3 x 38.3 mm, 82 parts (12 on the bottom side), 46 nets.

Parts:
C1: 620pF; C_0402_1005Metric_Pad0.74x0.62mm_HandSolder
C2, C12, C14, C32, C42: 10uF; C_0805_2012Metric_Pad1.18x1.45mm_HandSolder
C3: 22uF; C_0805_2012Metric_Pad1.18x1.45mm_HandSolder
C4, C31: .1uF; C_0603_1608Metric_Pad1.08x0.95mm_HandSolder
C5, C6, C9, C10, C38, C39, C40, C41: 270pF; C_0603_1608Metric_Pad1.08x0.95mm_HandSolder
C7, C8, C35, C36: 680pF; C_0603_1608Metric_Pad1.08x0.95mm_HandSolder
C11, C19, C20, C22, C25, C27, C29, C34: 1uF; C_0603_1608Metric_Pad1.08x0.95mm_HandSolder
C13, C15, C33, C43: 100nF; C_0603_1608Metric_Pad1.08x0.95mm_HandSolder
C16, C18, C21, C23, C26, C28, C30, C37: 1uF; C_0805_2012Metric_Pad1.18x1.45mm_HandSolder
C17, C24: .1pF; C_0402_1005Metric_Pad0.74x0.62mm_HandSolder
H1, H2, H3, H4: MountingHole; MountingHole_2.5mm
J2, J4: Conn_01x04; Molex_Micro-Lock_2200980471_1x04_P1.25mm_Horizontal
J3, J5: Conn_Coaxial; SMA_Molex_73251-2120_EdgeMount_Horizontal
L1: 2.2uH; IND_VLS3012CX-2R2M-1
R1: 100k; R_01005_0402Metric_Pad0.57x0.30mm_HandSolder
R3, R4, R5, R6, R7, R8, R19, R20: 10; R_0603_1608Metric_Pad0.98x0.95mm_HandSolder
R9, R10, R11, R12, R15, R16, R17, R18: 1000; R_0603_1608Metric_Pad0.98x0.95mm_HandSolder
R13, R14: 1G; R_2512_6332Metric_Pad1.40x3.35mm_HandSolder
U2, U10: LMP7721MA/NOPB; M08A
U3, U11: LMP2022MA/NOPB; M08A
U4, U5, U8, U9: AD8475ARMZ; RM_10_ADI
U6: TPS62153; VQFN-16-1EP_3x3mm_P0.5mm_EP1.68x1.68mm_ThermalVias
U7, U12: AD7176-2BRUZ; RU_24_ADI

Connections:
+3V3: C14.2, C15.2, C42.2, C43.2, J2.3, U7.16 (IOVDD), U12.16 (IOVDD)
+5V: C3.1, C12.2, C13.2, C19.2, C20.2, C22.2, C25.2, C27.2, C29.2, C32.2, C33.2, L1.2, R1.2, U2.6 (V+), U3.8 (V+), U4.3 (VS+), U5.3 (VS+), U6.7 (FSW), U6.14 (VOS), U7.7 (AVDD1), U7.8 (AVDD2), U8.3 (VS+), U9.3 (VS+), U10.6 (V+), U11.8 (V+), U12.7 (AVDD1), U12.8 (AVDD2)
/+VBAT: C2.1, J2.4, U6.10 (VIN), U6.11 (VIN), U6.12 (VIN), U6.13 (EN)
/E-Spray Plume Measurement 1/1_IN0.8+: R9.2, U3.7 (OUTB), U4.10 (IN0.8X+)
/E-Spray Plume Measurement 1/2_IN0.8+: R11.2, U3.1 (OUTA), U5.10 (IN0.8X+)
/E-Spray Plume Measurement 1/+2.5V: C4.1, C5.2, C6.1, C9.2, C10.1, C18.2, C19.1, C20.1, C21.2, C22.1, C23.2, J5.2 (Ext), U2.1 (IN+), U2.2 (NC), U2.7 (NC), U3.3 (INA+), U3.5 (INB+), U4.1 (IN0.8X-), U4.4 (VOCM), U5.1 (IN0.8X-), U5.4 (VOCM), U7.4 (REFOUT)
/E-Spray Plume Measurement 1/+OUT_1: R8.2, U4.5 (OUT+)
/E-Spray Plume Measurement 1/+OUT_2: R4.2, U5.5 (OUT+)
/E-Spray Plume Measurement 1/-OUT_1: R7.2, U4.6 (OUT-)
/E-Spray Plume Measurement 1/-OUT_2: R3.2, U5.6 (OUT-)
/E-Spray Plume Measurement 1/Amplified_Plume_1: C17.2, R10.1, R12.1, R13.1, U2.4 (OUT)
/E-Spray Plume Measurement 1/Plume_1: C17.1, J5.1 (In), R13.2, U2.8 (IN-)
/E-Spray Plume Measurement 2/3_IN0.8+: R17.2, U8.10 (IN0.8X+), U11.7 (OUTB)
/E-Spray Plume Measurement 2/4_IN0.8+: R15.2, U9.10 (IN0.8X+), U11.1 (OUTA)
/E-Spray Plume Measurement 2/+2.5V: C25.1, C26.2, C27.1, C28.2, C29.1, C30.2, C31.1, C38.2, C39.1, C40.2, C41.1, J3.2 (Ext), U8.1 (IN0.8X-), U8.4 (VOCM), U9.1 (IN0.8X-), U9.4 (VOCM), U10.1 (IN+), U10.2 (NC), U10.7 (NC), U11.3 (INA+), U11.5 (INB+), U12.4 (REFOUT)
/E-Spray Plume Measurement 2/+OUT_3: R19.2, U8.5 (OUT+)
/E-Spray Plume Measurement 2/+OUT_4: R5.2, U9.5 (OUT+)
/E-Spray Plume Measurement 2/-OUT_3: R20.2, U8.6 (OUT-)
/E-Spray Plume Measurement 2/-OUT_4: R6.2, U9.6 (OUT-)
/E-Spray Plume Measurement 2/Amplified_Plume_2: C24.2, R14.1, R16.1, R18.1, U10.4 (OUT)
/E-Spray Plume Measurement 2/Plume_2: C24.1, J3.1 (In), R14.2, U10.8 (IN-)
/PM_CS_1: J4.4, U7.14 (*CS)
/PM_CS_2: J2.1, U12.14 (*CS)
/SPI1_MISO: J4.1, U7.11 (DOUT/*RDY), U12.11 (DOUT/*RDY)
/SPI1_MOSI: J4.2, U7.12 (DIN), U12.12 (DIN)
/SPI1_SCK: J4.3, U7.13 (SCLK), U12.13 (SCLK)
GND: C1.2, C2.2, C3.2, C4.2, C11.2, C12.1, C13.1, C14.1, C15.1, C16.1, C18.1, C21.1, C23.1, C26.1, C28.1, C30.1, C31.2, C32.1, C33.1, C34.2, C37.1, C42.1, C43.1, J2.2, U2.3 (V-), U3.4 (V-), U4.8 (VS-), U5.8 (VS-), U6.5 (FB), U6.6 (GND), U6.8 (DEF), U6.15 (GND), U6.16 (GND), U6.17 (GND), U7.6 (AVSS), U7.17 (DGND), U8.8 (VS-), U9.8 (VS-), U10.3 (V-), U11.4 (V-), U12.6 (AVSS), U12.17 (DGND)
unnamed: L1.1, U6.1 (SW), U6.2 (SW), U6.3 (SW)
unnamed: R11.1, R12.2, U3.2 (INA-)
unnamed: R9.1, R10.2, U3.6 (INB-)
unnamed: R1.1, U6.4 (PG)
unnamed: C1.1, U6.9 (SS/TR)
unnamed: C8.2, C10.2, R7.1, U7.21 (AIN0)
unnamed: C8.1, C9.1, R8.1, U7.22 (AIN1)
unnamed: C6.2, C7.2, R3.1, U7.23 (AIN2)
unnamed: C5.1, C7.1, R4.1, U7.24 (AIN3)
unnamed: C11.1, U7.5 (REGCAPA)
unnamed: C16.2, U7.18 (REGCAPD)
unnamed: R15.1, R16.2, U11.2 (INA-)
unnamed: R17.1, R18.2, U11.6 (INB-)
unnamed: C36.2, C41.2, R20.1, U12.21 (AIN0)
unnamed: C36.1, C40.1, R19.1, U12.22 (AIN1)
unnamed: C35.2, C39.2, R6.1, U12.23 (AIN2)
unnamed: C35.1, C38.1, R5.1, U12.24 (AIN3)
unnamed: C34.1, U12.5 (REGCAPA)
unnamed: C37.2, U12.18 (REGCAPD)

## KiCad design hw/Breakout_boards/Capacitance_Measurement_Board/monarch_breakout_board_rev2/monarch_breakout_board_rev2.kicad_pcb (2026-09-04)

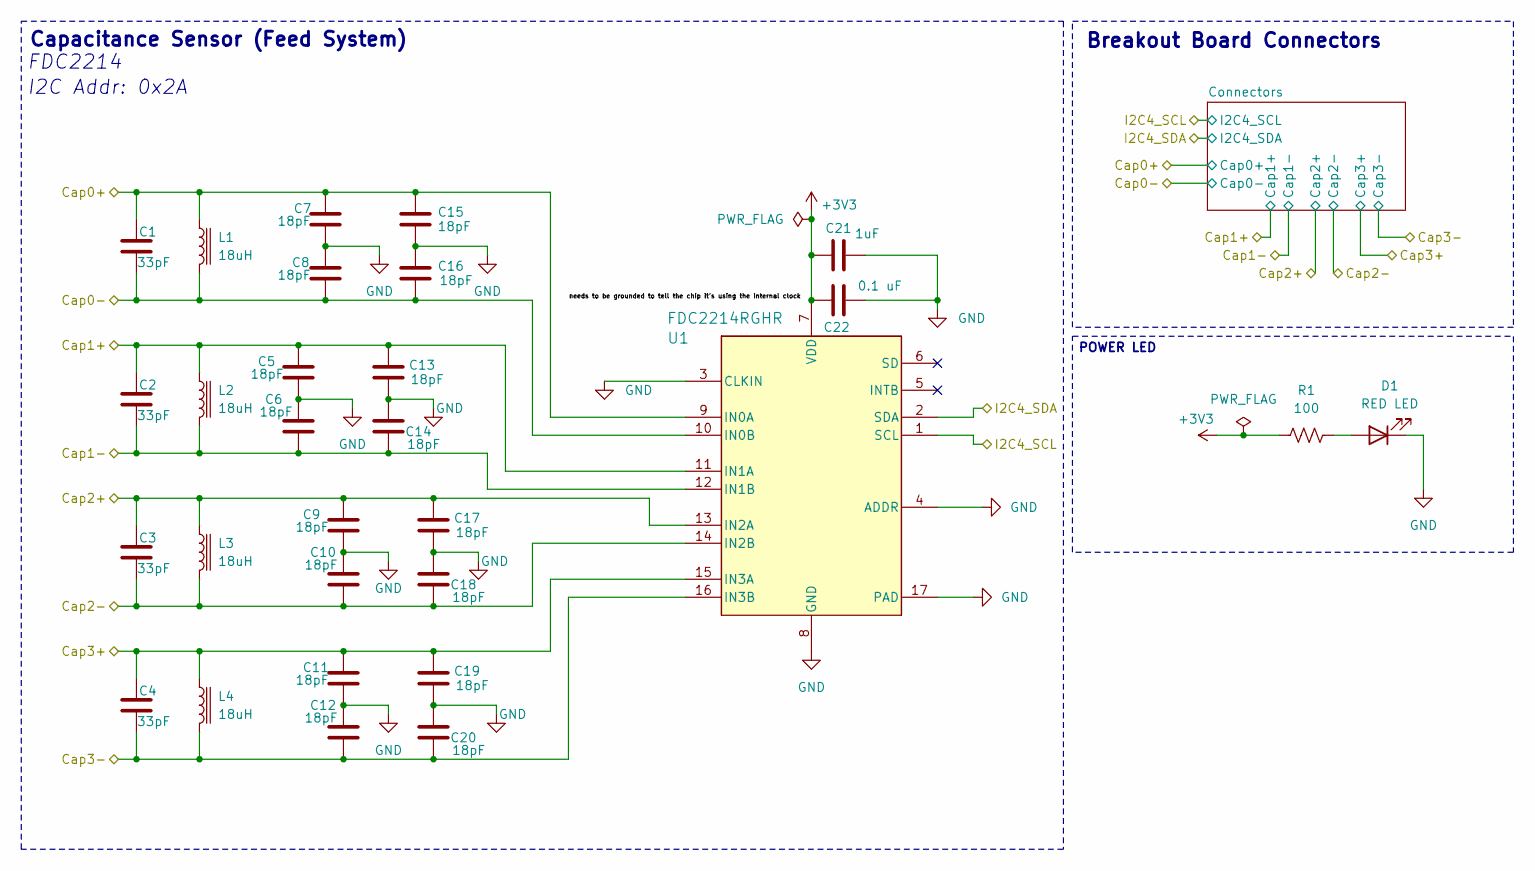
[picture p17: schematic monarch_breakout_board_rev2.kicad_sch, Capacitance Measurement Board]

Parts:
C1, C2, C3, C4: 33pF; C_0603_1608Metric
C5, C6, C7, C8, C9, C10, C11, C12, C13, C14, C15, C16, C17, C18, C19, C20: 18pF; C_0603_1608Metric
C21: 1uF; C_0603_1608Metric
C22: 0.1 uF; C_0603_1608Metric
D1: RED LED; LED_0603_1608Metric_Pad1.05x0.95mm_HandSolder
L1, L2, L3, L4: 18uH; INDM3225X240N
R1: 100; R_0603_1608Metric_Pad0.98x0.95mm_HandSolder
U1: FDC2214RGHR; RGH0016A

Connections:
+3V3: C21.2, C22.2, R1.1, U1.7 (VDD); also elsewhere on the board
/Cap0+: C1.1, C7.1, C15.1, L1.1, U1.9 (IN0A); also elsewhere on the board
/Cap0-: C1.2, C8.2, C16.2, L1.2, U1.10 (IN0B); also elsewhere on the board
/Cap1+: C2.1, C5.1, C13.1, L2.1, U1.11 (IN1A); also elsewhere on the board
/Cap1-: C2.2, C6.2, C14.2, L2.2, U1.12 (IN1B); also elsewhere on the board
/Cap2+: C3.1, C9.1, C17.1, L3.1, U1.13 (IN2A); also elsewhere on the board
/Cap2-: C3.2, C10.2, C18.2, L3.2, U1.14 (IN2B); also elsewhere on the board
/Cap3+: C4.1, C11.1, C19.1, L4.1, U1.15 (IN3A); also elsewhere on the board
/Cap3-: C4.2, C12.2, C20.2, L4.2, U1.16 (IN3B); also elsewhere on the board
/I2C4_SCL: U1.1 (SCL); also elsewhere on the board
/I2C4_SDA: U1.2 (SDA); also elsewhere on the board
GND: C5.2, C6.1, C7.2, C8.1, C9.2, C10.1, C11.2, C12.1, C13.2, C14.1, C15.2, C16.1, C17.2, C18.1, C19.2, C20.1, C21.1, C22.1, D1.1 (K), U1.3 (CLKIN), U1.4 (ADDR), U1.8 (GND), U1.17 (PAD), U1.V; also elsewhere on the board
unnamed: D1.2 (A), R1.2

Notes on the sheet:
POWER LED
I2C Addr: 0x2A
Breakout Board Connectors
FDC2214
Capacitance Sensor (Feed System)

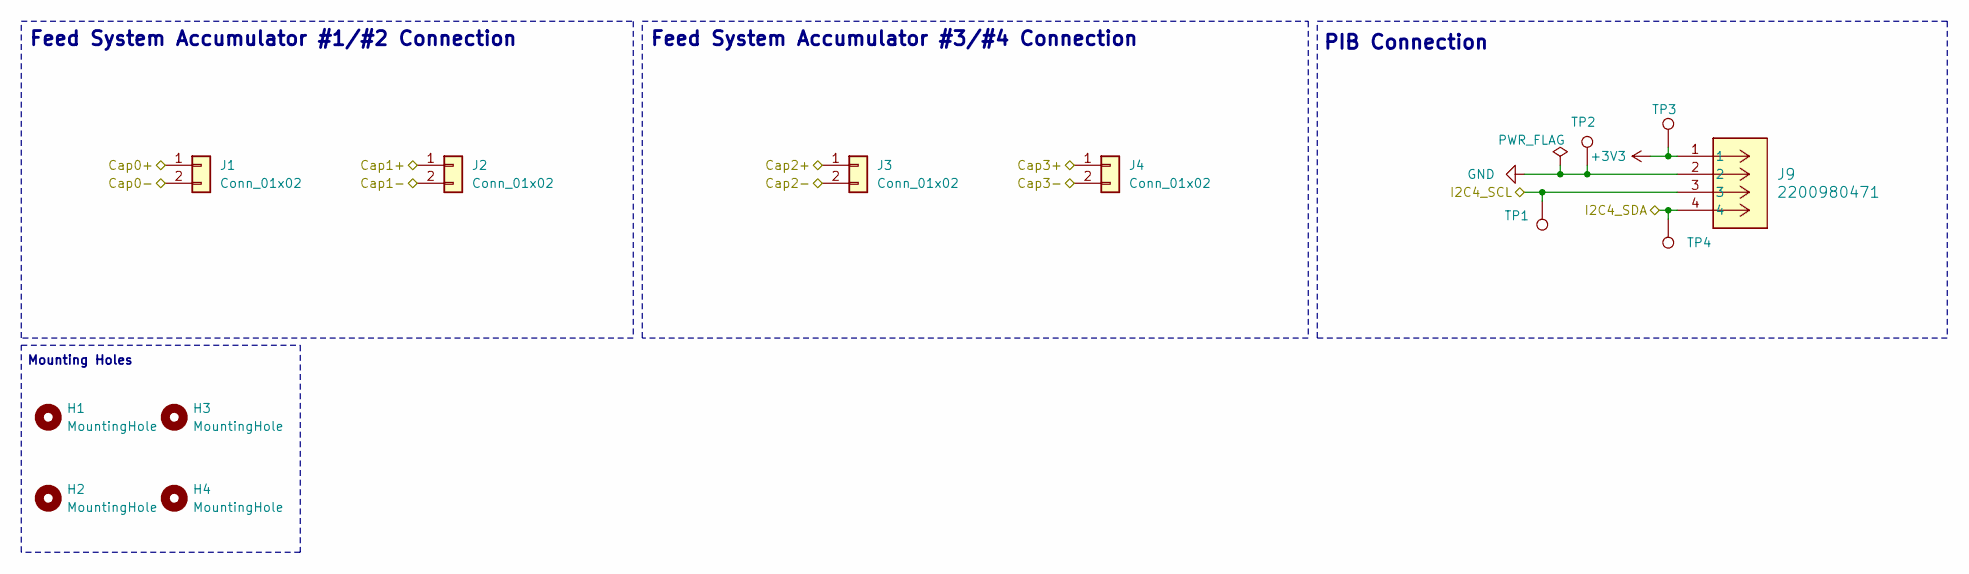
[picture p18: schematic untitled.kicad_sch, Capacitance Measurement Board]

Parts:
H1, H2, H3, H4: MountingHole; MountingHole_2.2mm_M2_DIN965_Pad
J1, J2, J3, J4: Conn_01x02; Molex_Micro-Lock_2200980271_1x02_P1.25mm_Horizontal
J9: 2200980471; Molex_Micro-Lock_2200980471_1x04_P1.25mm_Horizontal
TP1, TP2, TP3, TP4: TestPoint; TestPoint_Keystone_5000-5004_Miniature

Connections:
+3V3: J9.1, TP3.1; also elsewhere on the board
/Cap0+: J1.1; also elsewhere on the board
/Cap0-: J1.2; also elsewhere on the board
/Cap1+: J2.1; also elsewhere on the board
/Cap1-: J2.2; also elsewhere on the board
/Cap2+: J3.1; also elsewhere on the board
/Cap2-: J3.2; also elsewhere on the board
/Cap3+: J4.1; also elsewhere on the board
/Cap3-: J4.2; also elsewhere on the board
/I2C4_SCL: J9.3, TP1.1; also elsewhere on the board
/I2C4_SDA: J9.4, TP4.1; also elsewhere on the board
GND: J9.2, TP2.1; also elsewhere on the board

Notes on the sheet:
Mounting Holes
PIB Connection
Feed System Accumulator #1/#2 Connection
Feed System Accumulator #3/#4 Connection

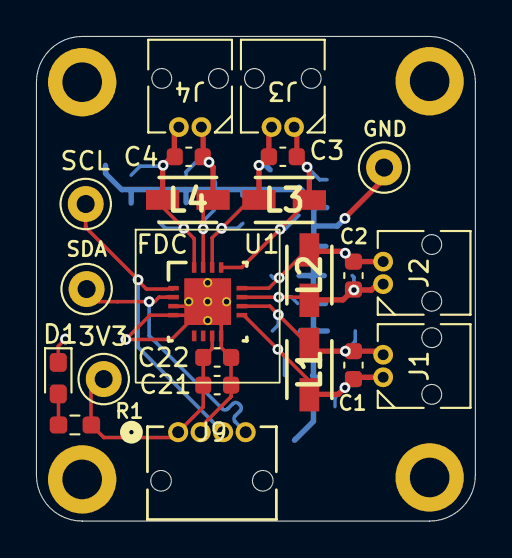
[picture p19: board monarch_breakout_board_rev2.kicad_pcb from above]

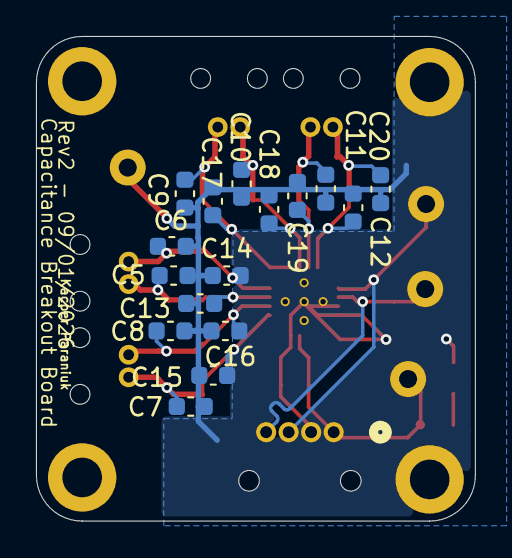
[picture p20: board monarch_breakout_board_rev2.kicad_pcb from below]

Board: 2 copper layers, 24.4 x 26.9 mm, 42 parts (16 on the bottom side), 13 nets.

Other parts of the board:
3V3: TestPoint; TestPoint_Keystone_5000-5004_Miniature
GND: TestPoint; TestPoint_Keystone_5000-5004_Miniature
SCL: TestPoint; TestPoint_Keystone_5000-5004_Miniature
SDA: TestPoint; TestPoint_Keystone_5000-5004_Miniature

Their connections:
+3V3: 3V3.1 (1_1); also elsewhere on the board
/I2C4_SCL: SCL.1 (1_1); also elsewhere on the board
/I2C4_SDA: SDA.1 (1_1); also elsewhere on the board
GND: GND.1 (1_1); also elsewhere on the board

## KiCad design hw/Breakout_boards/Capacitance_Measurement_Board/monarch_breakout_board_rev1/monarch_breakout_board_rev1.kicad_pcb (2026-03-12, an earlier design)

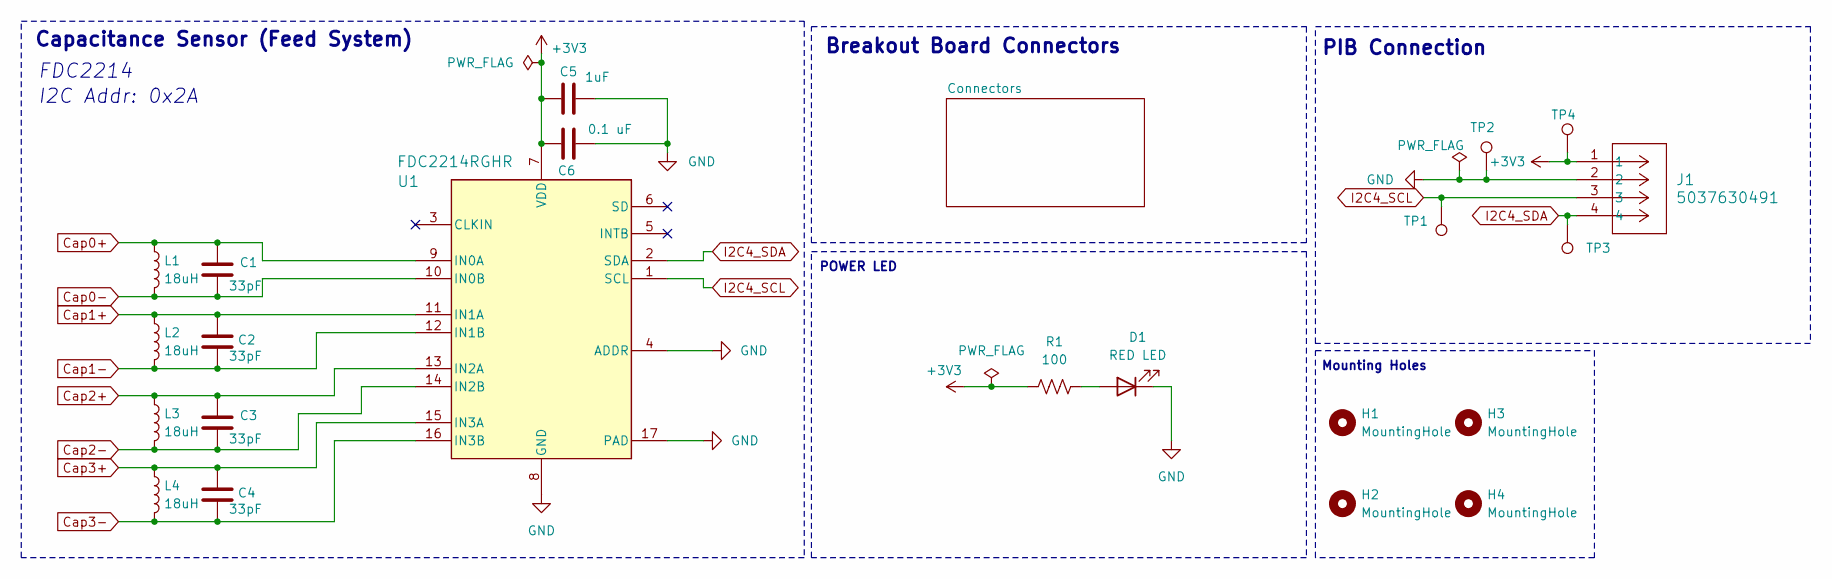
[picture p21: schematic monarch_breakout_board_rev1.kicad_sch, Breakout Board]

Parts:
C1, C2, C3, C4: 33pF; C_0603_1608Metric
C5: 1uF; C_0603_1608Metric
C6: 0.1 uF; C_0603_1608Metric
D1: RED LED; LED_0603_1608Metric_Pad1.05x0.95mm_HandSolder
H1, H2, H3, H4: MountingHole; MountingHole_2.2mm_M2_DIN965_Pad
J1: 5037630491; CONN_5037630000-SD_04_MOL
L1, L2, L3, L4: 18uH; L_0805_2012Metric
R1: 100; R_0603_1608Metric_Pad0.98x0.95mm_HandSolder
TP1, TP2, TP3, TP4: TestPoint; TestPoint_Keystone_5000-5004_Miniature
U1: FDC2214RGHR; RGH0016A

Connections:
+3V3: C5.2, C6.2, J1.1, R1.1, TP4.1, U1.7 (VDD)
Cap0+: C1.1, L1.1, U1.9 (IN0A); also elsewhere on the board
Cap0-: C1.2, L1.2, U1.10 (IN0B); also elsewhere on the board
Cap1+: C2.1, L2.1, U1.11 (IN1A); also elsewhere on the board
Cap1-: C2.2, L2.2, U1.12 (IN1B); also elsewhere on the board
Cap2+: C3.1, L3.1, U1.13 (IN2A); also elsewhere on the board
Cap2-: C3.2, L3.2, U1.14 (IN2B); also elsewhere on the board
Cap3+: C4.1, L4.1, U1.15 (IN3A); also elsewhere on the board
Cap3-: C4.2, L4.2, U1.16 (IN3B); also elsewhere on the board
GND: C5.1, C6.1, D1.1 (K), J1.2, TP2.1, U1.4 (ADDR), U1.8 (GND), U1.17 (PAD), U1.V
I2C4_SCL: J1.3, TP1.1, U1.1 (SCL)
I2C4_SDA: J1.4, TP3.1, U1.2 (SDA)
unnamed: D1.2 (A), R1.2

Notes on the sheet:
POWER LED
I2C Addr: 0x2A
PIB Connection
Breakout Board Connectors
Mounting Holes
FDC2214
Capacitance Sensor (Feed System)

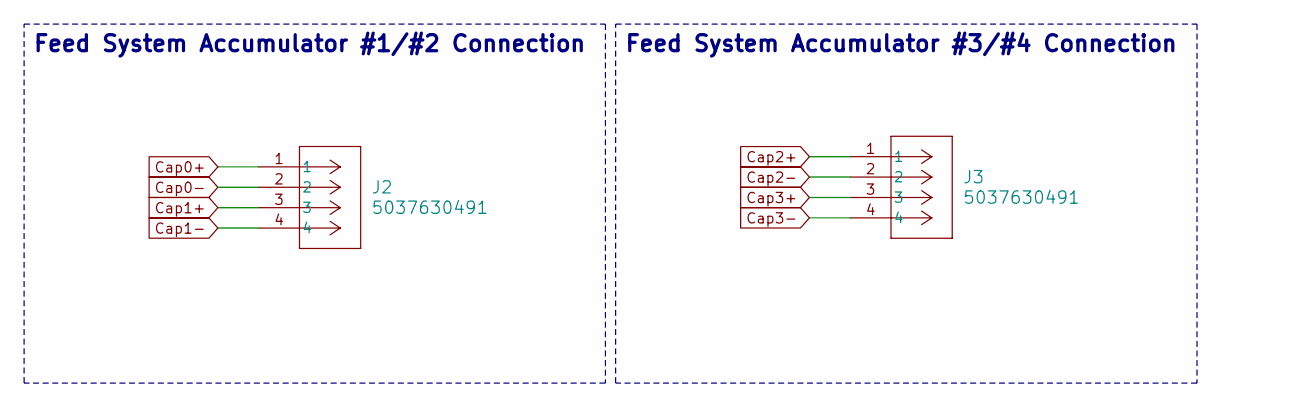
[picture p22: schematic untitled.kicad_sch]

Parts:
J2, J3: 5037630491; CONN_5037630000-SD_04_MOL

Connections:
Cap0+: J2.1; also elsewhere on the board
Cap0-: J2.2; also elsewhere on the board
Cap1+: J2.3; also elsewhere on the board
Cap1-: J2.4; also elsewhere on the board
Cap2+: J3.1; also elsewhere on the board
Cap2-: J3.2; also elsewhere on the board
Cap3+: J3.3; also elsewhere on the board
Cap3-: J3.4; also elsewhere on the board

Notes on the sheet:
Feed System Accumulator #1/#2 Connection
Feed System Accumulator #3/#4 Connection

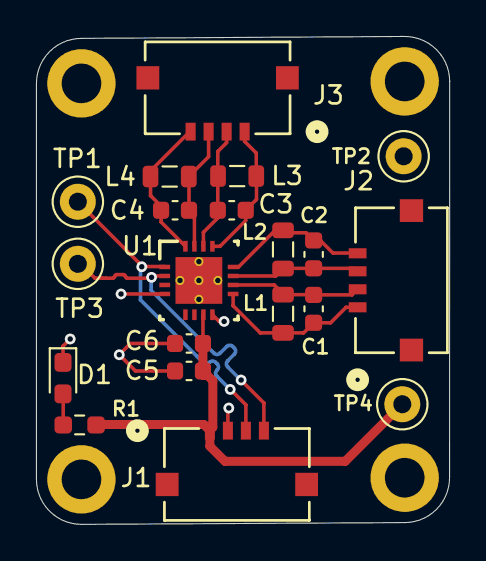
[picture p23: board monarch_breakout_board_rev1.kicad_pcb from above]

Board: 2 copper layers, 23.0 x 27.1 mm, 24 parts (0 on the bottom side), 13 nets.

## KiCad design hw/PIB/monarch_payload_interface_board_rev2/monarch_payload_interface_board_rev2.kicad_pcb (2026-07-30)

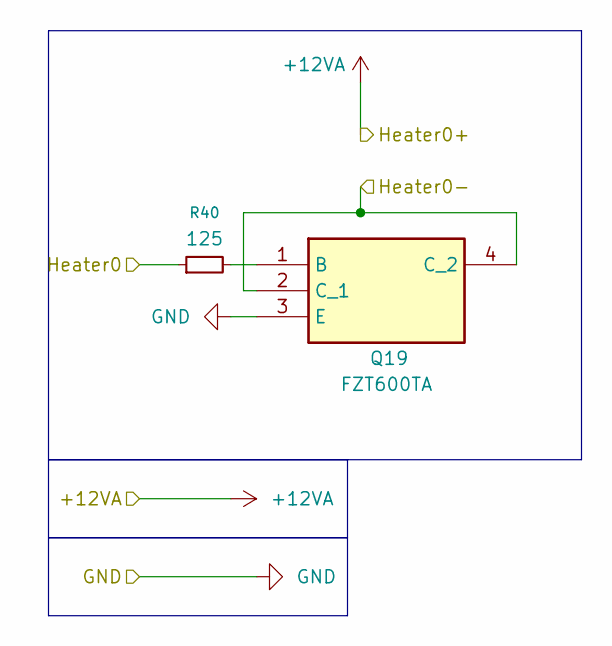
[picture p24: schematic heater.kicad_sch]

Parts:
Q19: FZT600TA; SOT230P700X170-4N; Mouser Part Number 522-FZT600TA
R40: 125; R_0603_1608Metric

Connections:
12VA_VA-: Q19.3 (E); also elsewhere on the board
/Connectors/Heater0-: Q19.2 (C_1), Q19.4 (C_2); also elsewhere on the board
/Heater/Heater0: R40.1; also elsewhere on the board
unnamed: Q19.1 (B), R40.2

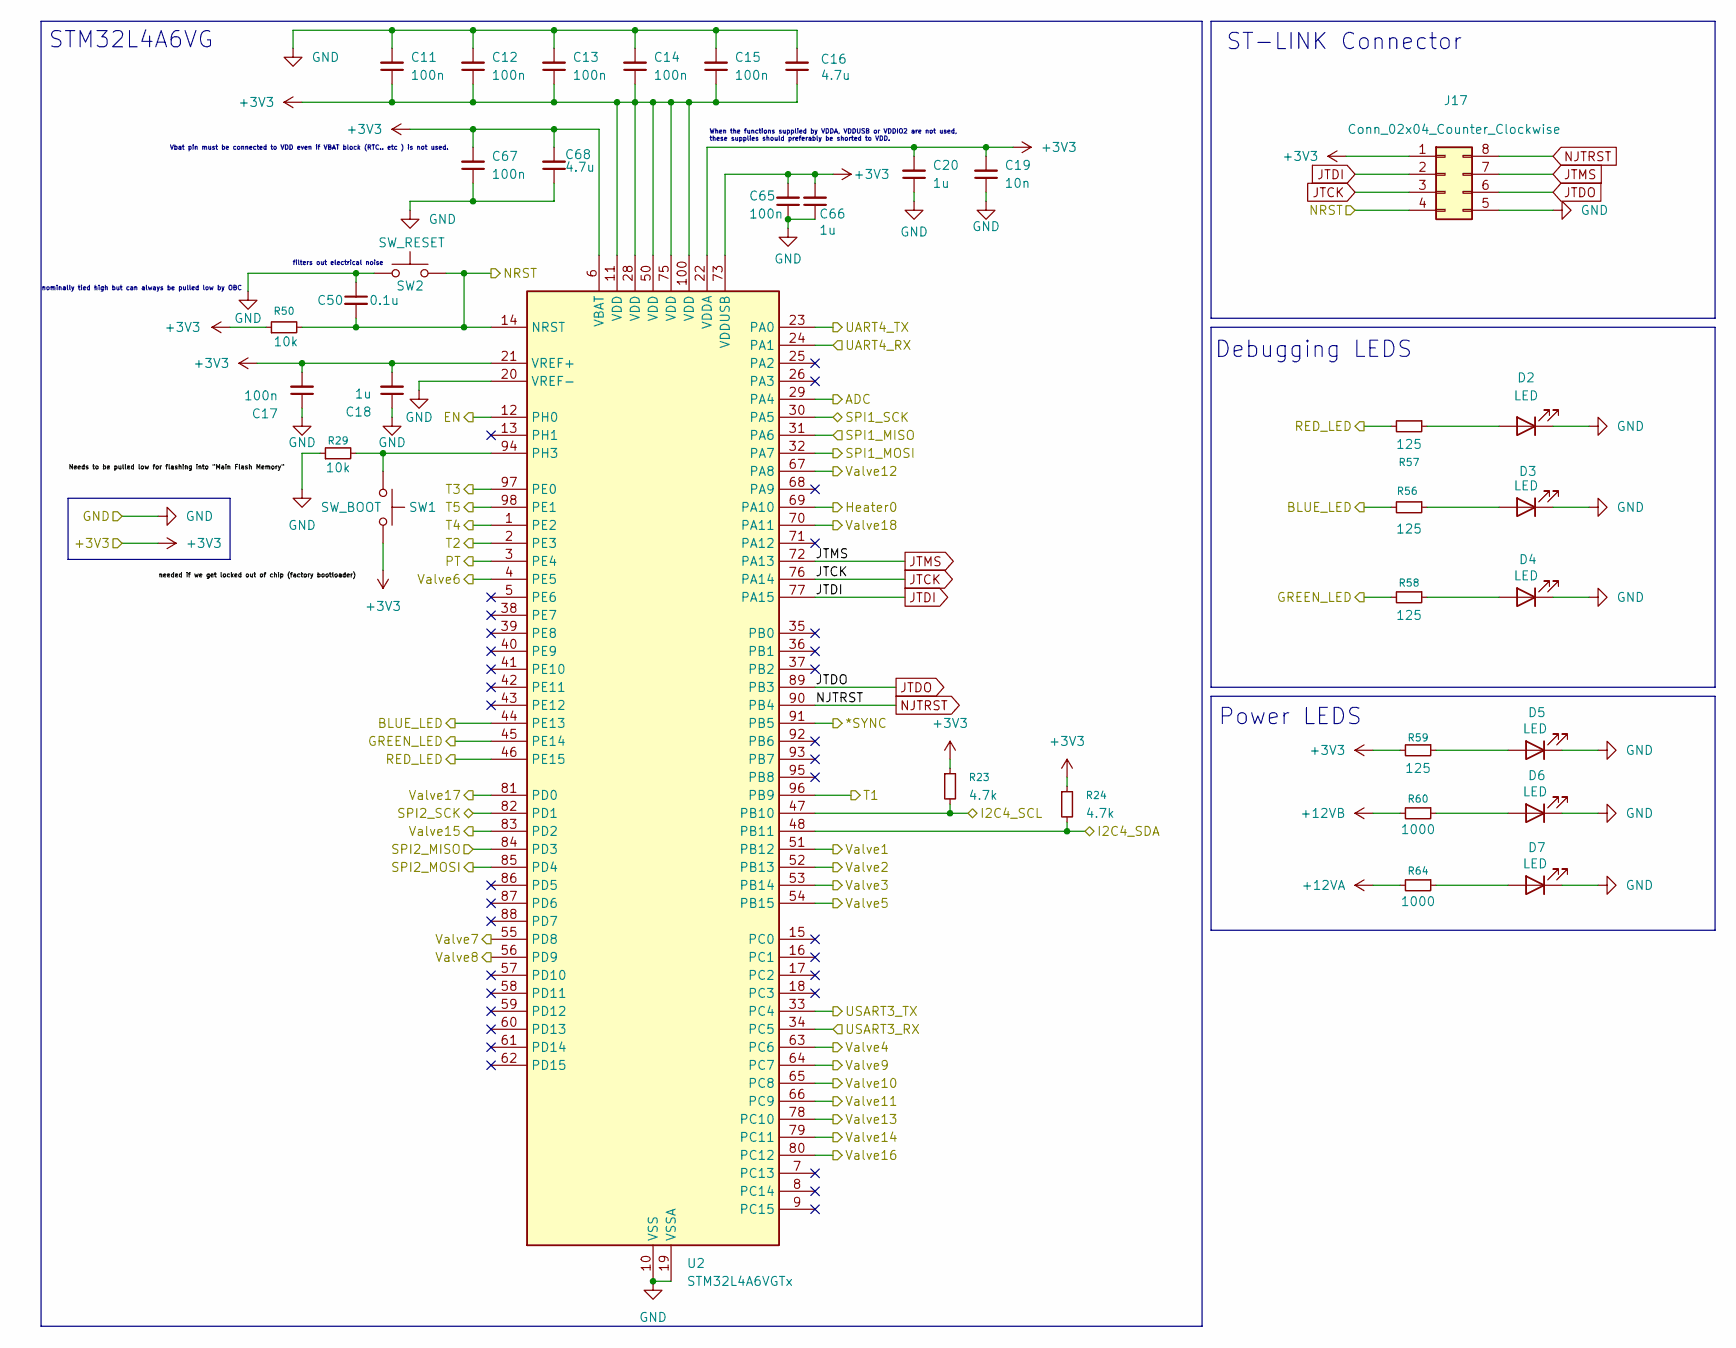
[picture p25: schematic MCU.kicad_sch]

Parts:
C11, C12, C13, C14, C15, C17, C65, C67: 100n; C_0603_1608Metric
C16, C68: 4.7u; C_0603_1608Metric
C18, C20, C66: 1u; C_0603_1608Metric
C19: 10n; C_0603_1608Metric
C50: 0.1u; C_0603_1608Metric
D2, D3, D4, D5, D6, D7: LED; LED_0603_1608Metric
J17: Conn_02x04_Counter_Clockwise; PinHeader_2x04_P2.54mm_Vertical
R23, R24: 4.7k; R_0603_1608Metric
R29, R50: 10k; R_0603_1608Metric
R56, R57, R58, R59: 125; R_0603_1608Metric
R60, R64: 1000; R_0603_1608Metric
SW1: SW_BOOT; PinHeader_1x02_P1.00mm_Vertical
SW2: SW_RESET; PinHeader_1x02_P1.00mm_Vertical
U2: STM32L4A6VGTx; LQFP-100_14x14mm_P0.5mm

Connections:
12VA_VA-: C11.2, C12.2, C13.2, C14.2, C15.2, C16.2, C17.1, C18.1, C19.1, C20.1, C50.1, C65.1, C66.1, C67.1, C68.1, D2.1 (K), D3.1 (K), D4.1 (K), D5.1 (K), D6.1 (K), D7.1 (K), J17.5, R29.1, SW2.1, U2.10 (VSS), U2.19 (VSSA), U2.20 (VREF-), U2.27 (VSS), U2.49 (VSS), U2.74 (VSS), U2.99 (VSS); also elsewhere on the board
+3V3: C11.1, C12.1, C13.1, C14.1, C15.1, C16.1, C17.2, C18.2, C19.2, C20.2, C65.2, C66.2, C67.2, C68.2, J17.1, R23.1, R24.1, R50.1, R59.2, SW1.2, U2.6 (VBAT), U2.11 (VDD), U2.21 (VREF+), U2.22 (VDDA), U2.28 (VDD), U2.50 (VDD), U2.73 (VDDUSB), U2.75 (VDD), U2.100 (VDD); also elsewhere on the board
+12VA: R64.2; also elsewhere on the board
+12VB: R60.2; also elsewhere on the board
/12V Power Supply/EN: U2.12 (PH0); also elsewhere on the board
/Connectors/*SYNC: U2.91 (PB5); also elsewhere on the board
/Connectors/ADC: U2.29 (PA4); also elsewhere on the board
/Connectors/I2C4_SCL: R23.2, U2.47 (PB10); also elsewhere on the board
/Connectors/I2C4_SDA: R24.2, U2.48 (PB11); also elsewhere on the board
/Connectors/PT: U2.3 (PE4); also elsewhere on the board
/Connectors/SPI1_MISO: U2.31 (PA6); also elsewhere on the board
/Connectors/SPI1_MOSI: U2.32 (PA7); also elsewhere on the board
/Connectors/SPI1_SCK: U2.30 (PA5); also elsewhere on the board
/Connectors/SPI2_MISO: U2.84 (PD3); also elsewhere on the board
/Connectors/SPI2_MOSI: U2.85 (PD4); also elsewhere on the board
/Connectors/SPI2_SCK: U2.82 (PD1); also elsewhere on the board
/Connectors/T1: U2.96 (PB9); also elsewhere on the board
/Connectors/T2: U2.2 (PE3); also elsewhere on the board
/Connectors/T3: U2.97 (PE0); also elsewhere on the board
/Connectors/T4: U2.1 (PE2); also elsewhere on the board
/Connectors/T5: U2.98 (PE1); also elsewhere on the board
/Connectors/UART_PPU_RX: U2.23 (PA0); also elsewhere on the board
/Connectors/UART_PPU_TX: U2.24 (PA1); also elsewhere on the board
/Connectors/USART3_RX: U2.34 (PC5); also elsewhere on the board
/Connectors/USART3_TX: U2.33 (PC4); also elsewhere on the board
/Heater/Heater0: U2.69 (PA10); also elsewhere on the board
/MCU/BLUE_LED: R56.2, U2.44 (PE13)
/MCU/GREEN_LED: R58.2, U2.45 (PE14)
/MCU/NRST: C50.2, J17.4, R50.2, SW2.2, U2.14 (NRST); also elsewhere on the board
/MCU/RED_LED: R57.2, U2.46 (PE15)
/MCU/Valve1: U2.51 (PB12); also elsewhere on the board
/MCU/Valve2: U2.52 (PB13); also elsewhere on the board
/MCU/Valve3: U2.53 (PB14); also elsewhere on the board
/MCU/Valve4: U2.63 (PC6); also elsewhere on the board
/MCU/Valve5: U2.54 (PB15); also elsewhere on the board
/MCU/Valve6: U2.4 (PE5); also elsewhere on the board
/MCU/Valve7: U2.55 (PD8); also elsewhere on the board
/MCU/Valve8: U2.56 (PD9); also elsewhere on the board
/MCU/Valve9: U2.64 (PC7); also elsewhere on the board
/MCU/Valve10: U2.65 (PC8); also elsewhere on the board
/MCU/Valve11: U2.66 (PC9); also elsewhere on the board
/MCU/Valve12: U2.67 (PA8); also elsewhere on the board
/MCU/Valve13: U2.78 (PC10); also elsewhere on the board
/MCU/Valve14: U2.79 (PC11); also elsewhere on the board
/MCU/Valve15: U2.83 (PD2); also elsewhere on the board
/MCU/Valve16: U2.80 (PC12); also elsewhere on the board
/MCU/Valve17: U2.81 (PD0); also elsewhere on the board
/MCU/Valve18: U2.70 (PA11); also elsewhere on the board
JTCK: J17.3, U2.76 (PA14)
JTDI: J17.2, U2.77 (PA15)
JTDO: J17.6, U2.89 (PB3)
JTMS: J17.7, U2.72 (PA13)
NJTRST: J17.8, U2.90 (PB4)
unnamed: D2.2 (A), R57.1
unnamed: D3.2 (A), R56.1
unnamed: D4.2 (A), R58.1
unnamed: D5.2 (A), R59.1
unnamed: D6.2 (A), R60.1
unnamed: D7.2 (A), R64.1
unnamed: R29.2, SW1.1, U2.94 (PH3)

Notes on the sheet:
nominally tied high but can always be pulled low by OBC
Debugging LEDS
filters out electrical noise
Power LEDS
When the functions supplied by VDDA, VDDUSB or VDDIO2 are not used, these supplies should preferably be shorted to VDD.
ST-LINK Connector
Vbat pin must be connected to VDD even if VBAT block (RTC.. etc ) is not used.
STM32L4A6VG

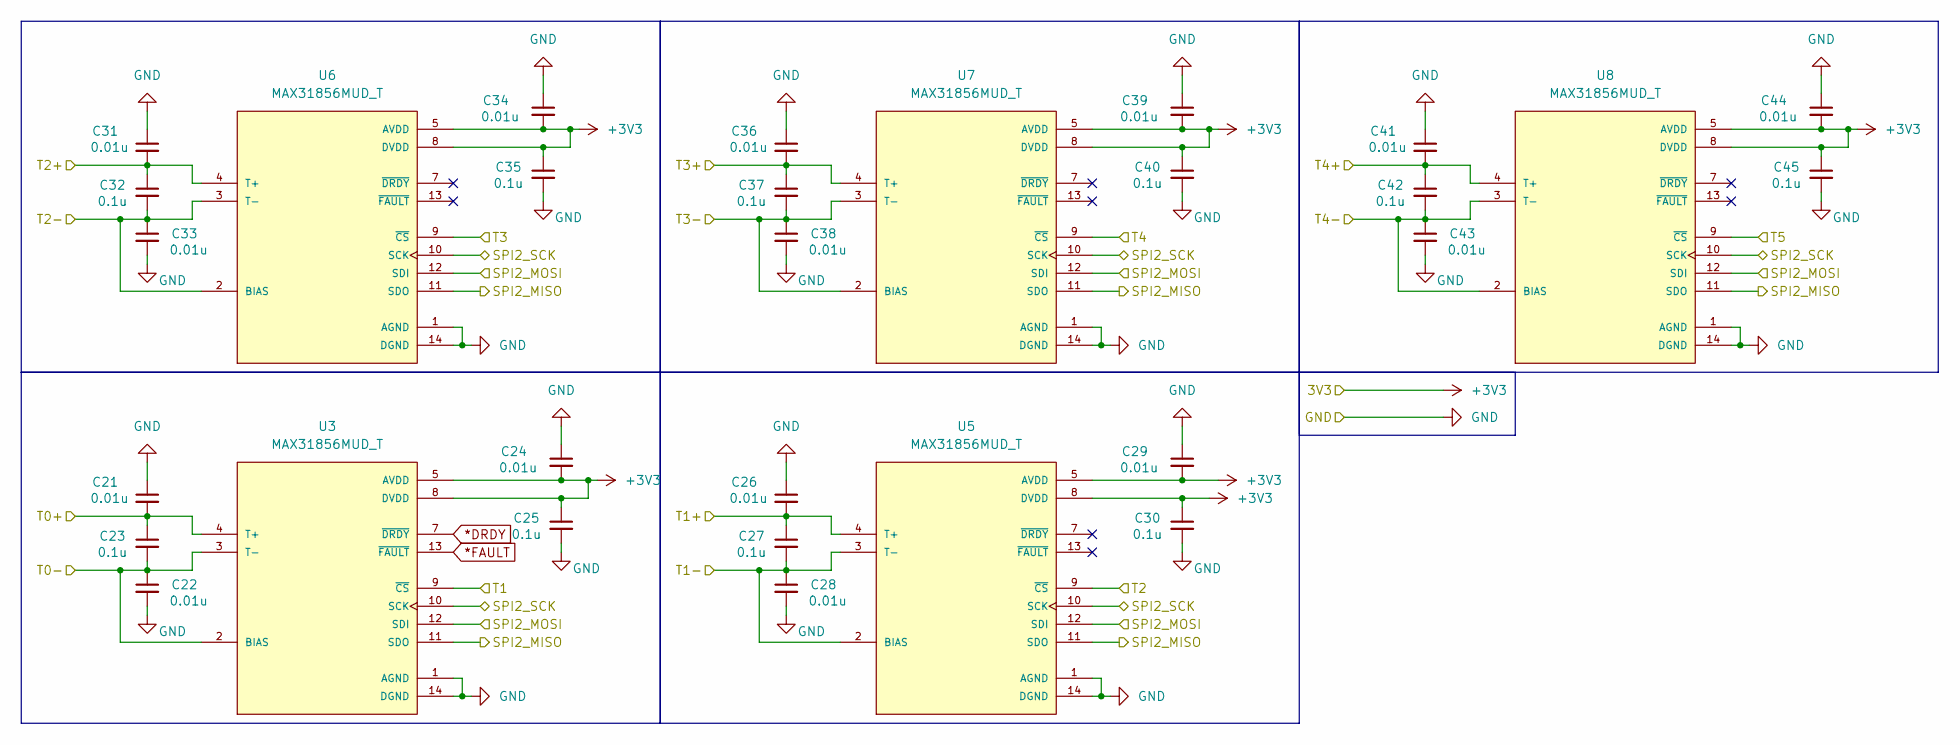
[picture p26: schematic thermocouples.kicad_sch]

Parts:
C21, C22, C24, C26, C28, C29, C31, C33, C34, C36, C38, C39, C41, C43, C44: 0.01u; C_0603_1608Metric
C23, C25, C27, C30, C32, C35, C37, C40, C42, C45: 0.1u; C_0603_1608Metric
U3, U5, U6, U7, U8: MAX31856MUD_T; SOP65P640X110-14N; PARTREV 0

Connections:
12VA_VA-: C21.1, C22.2, C24.1, C25.2, C26.1, C28.2, C29.1, C30.2, C31.1, C33.2, C34.1, C35.2, C36.1, C38.2, C39.1, C40.2, C41.1, C43.2, C44.1, C45.2, U3.1 (AGND), U3.14 (DGND), U5.1 (AGND), U5.14 (DGND), U6.1 (AGND), U6.14 (DGND), U7.1 (AGND), U7.14 (DGND), U8.1 (AGND), U8.14 (DGND); also elsewhere on the board
*DRDY: U3.7 (~DRDY); also elsewhere on the board
*FAULT: U3.13 (~FAULT); also elsewhere on the board
+3V3: C24.2, C25.1, C29.2, C30.1, C34.2, C35.1, C39.2, C40.1, C44.2, C45.1, U3.5 (AVDD), U3.8 (DVDD), U5.5 (AVDD), U5.8 (DVDD), U6.5 (AVDD), U6.8 (DVDD), U7.5 (AVDD), U7.8 (DVDD), U8.5 (AVDD), U8.8 (DVDD); also elsewhere on the board
/Connectors/SPI2_MISO: U3.11 (SDO), U5.11 (SDO), U6.11 (SDO), U7.11 (SDO), U8.11 (SDO); also elsewhere on the board
/Connectors/SPI2_MOSI: U3.12 (SDI), U5.12 (SDI), U6.12 (SDI), U7.12 (SDI), U8.12 (SDI); also elsewhere on the board
/Connectors/SPI2_SCK: U3.10 (SCK), U5.10 (SCK), U6.10 (SCK), U7.10 (SCK), U8.10 (SCK); also elsewhere on the board
/Connectors/T0+: C21.2, C23.1, U3.4 (T+); also elsewhere on the board
/Connectors/T0-: C22.1, C23.2, U3.2 (BIAS), U3.3 (T-); also elsewhere on the board
/Connectors/T1: U3.9 (~CS); also elsewhere on the board
/Connectors/T1+: C26.2, C27.1, U5.4 (T+); also elsewhere on the board
/Connectors/T1-: C27.2, C28.1, U5.2 (BIAS), U5.3 (T-); also elsewhere on the board
/Connectors/T2: U5.9 (~CS); also elsewhere on the board
/Connectors/T2+: C31.2, C32.1, U6.4 (T+); also elsewhere on the board
/Connectors/T2-: C32.2, C33.1, U6.2 (BIAS), U6.3 (T-); also elsewhere on the board
/Connectors/T3: U6.9 (~CS); also elsewhere on the board
/Connectors/T3+: C36.2, C37.1, U7.4 (T+); also elsewhere on the board
/Connectors/T3-: C37.2, C38.1, U7.2 (BIAS), U7.3 (T-); also elsewhere on the board
/Connectors/T4: U7.9 (~CS); also elsewhere on the board
/Connectors/T4+: C41.2, C42.1, U8.4 (T+); also elsewhere on the board
/Connectors/T4-: C42.2, C43.1, U8.2 (BIAS), U8.3 (T-); also elsewhere on the board
/Connectors/T5: U8.9 (~CS); also elsewhere on the board

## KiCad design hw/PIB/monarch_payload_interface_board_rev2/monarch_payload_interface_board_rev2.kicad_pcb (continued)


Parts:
C48, C49, C55, C69, C88, C89, C90, C91, C92, C93: 0.1u; C_0603_1608Metric
C56, C87: 1u; C_0603_1608Metric
R41, R43, R44, R51, R52, R61: 100k; R_0603_1608Metric
R42, R45: 300k; R_0603_1608Metric
R53, R54: 233k; R_0603_1608Metric
R62, R63: 312.5k; R_0603_1608Metric
R65: 10k; R_0603_1608Metric
TP1, TP2, TP3, TP4, TP5: TestPoint; TestPoint_Pad_D1.0mm
U1: Payload; PC104-Standard
U10: AD7124-8BCPZ-RL; CP-32-12_ADI
U11, U12, U13: WSK06121L000FEA; SMT_121L000FEA_VIS

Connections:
3V3_VA+: R61.2, R63.1, U10.10 (AIN6/IOUT/VBIAS)
3V3_VB+: R41.2, R62.1, U10.8 (AIN4/IOUT/VBIAS/P3)
12VA_VA+: R44.2, R45.1, U10.6 (AIN2/IOUT/VBIAS/P1)
12VA_VA-: C48.1, C49.1, C55.1, C56.1, C69.2, C87.1, C87.2, C88.1, C88.2, C89.1, C90.2, C91.2, C92.1, C92.2, C93.2, R41.1, R43.1, R44.1, R51.1, R52.1, R61.1, TP1.1 (1_1), U1.61 (09), U1.66 (14), U1.69 (17), U1.73 (21), U1.74 (22), U1.81 (29), U1.82 (30), U1.84 (32), U1.99 (47), U1.100 (48), U10.3 (DGND), U10.5 (AIN1/IOUT/VBIAS), U10.7 (AIN3/IOUT/VBIAS/P2), U10.9 (AIN5/IOUT/VBIAS/P4), U10.11 (AIN7/IOUT/VBIAS), U10.13 (REFIN1(-)), U10.15 (AIN9/IOUT/VBIAS), U10.17 (AIN11/IOUT/VBIAS), U10.19 (AIN13/IOUT/VBIAS), U10.21 (AIN15/IOUT/VBIAS/REFIN2(-)), U10.23 (AVSS), U10.33 (EP); also elsewhere on the board
12VA_VB+: R42.1, R43.2, U10.4 (AIN0/IOUT/VBIAS)
12VB_VA+: U10.18 (AIN12/IOUT/VBIAS); also elsewhere on the board
12VB_VB+: U10.20 (AIN14/IOUT/VBIAS/REFIN2(+)); also elsewhere on the board
+3V3: C55.2, C56.2, C69.1, C89.2, R65.2, TP5.1 (1_1), U10.2 (IOVDD), U10.26 (AVDD), U12.I1; also elsewhere on the board
+3V3_IN: U1.79 (27), U1.80 (28), U12.I2
+12VA: TP4.1 (1_1), U11.I1; also elsewhere on the board
+12VA_IN: U1.75 (23), U1.76 (24), U11.I2
+12VB: TP3.1 (1_1); also elsewhere on the board
/Connectors/*SYNC: R65.1, U10.27 (*SYNC); also elsewhere on the board
/Connectors/ADC: U10.32 (*CS); also elsewhere on the board
/Connectors/SPI1_MISO: U10.28 (DOUT/*RDY); also elsewhere on the board
/Connectors/SPI1_MOSI: U10.29 (DIN); also elsewhere on the board
/Connectors/SPI1_SCK: U10.30 (SCLK); also elsewhere on the board
/Connectors/USART3_RX: U1.35; also elsewhere on the board
/Connectors/USART3_TX: U1.33; also elsewhere on the board
/MCU/NRST: U1.31; also elsewhere on the board
unnamed: R42.2, U11.E1
unnamed: R45.2, U11.E2
unnamed: R53.2, U13.E1
unnamed: R54.2, U13.E2
unnamed: R62.2, U12.E1
unnamed: R63.2, U12.E2
unnamed: C90.1, C91.1, C93.1, U10.12 (REFIN1(+)), U10.22 (REFOUT)
unnamed: C48.2, U10.24 (REGCAPA)
unnamed: C49.2, U10.1 (REGCAPD)
VBAT: TP2.1 (1_1), U13.I2; also elsewhere on the board
VBAT_IN: U1.97 (45), U1.98 (46), U13.I1
VBAT_VA+: R51.2, R53.1, U10.14 (AIN8/IOUT/VBIAS)
VBAT_VB+: R52.2, R54.1, U10.16 (AIN10/IOUT/VBIAS)

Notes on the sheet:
Before all other Connections, measure currents:
AD7124-8
PC104 Stack Connections
exposed pad needs to be connected to GND according to datasheet


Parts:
CR1, CR2, CR3, CR4, CR5, CR6, CR7, CR8, CR9, CR10, CR11, CR12, CR13, CR14, CR15, CR16, CR17, CR18: S1J-13-F; SMA_DIO-L
Q1, Q2, Q3, Q4, Q5, Q6, Q7, Q8, Q9, Q10, Q11, Q12, Q13, Q14, Q15, Q16, Q17, Q18: FZT600TA; SOT230P700X170-4N; Mouser Part Number 522-FZT600TA
R1, R2, R3, R4, R5, R6, R7, R8, R9, R10, R11, R12, R13, R14, R15, R16, R30, R31: 125; R_0603_1608Metric
R22, R25, R26: 100k; R_0603_1608Metric

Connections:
12VA_VA-: Q1.3 (E), Q2.3 (E), Q3.3 (E), Q4.3 (E), Q5.3 (E), Q6.3 (E), Q7.3 (E), Q8.3 (E), Q9.3 (E), Q10.3 (E), Q11.3 (E), Q12.3 (E), Q13.3 (E), Q14.3 (E), Q15.3 (E), Q16.3 (E), Q17.3 (E), Q18.3 (E), R22.1, R25.1, R26.1; also elsewhere on the board
+12VA: CR1.1, CR2.1, CR3.1, CR5.1, CR7.1, CR8.1, CR9.1, CR10.1, CR11.1, CR12.1, CR13.1, CR14.1, CR15.1, CR16.1, CR17.1, CR18.1; also elsewhere on the board
+12VB: CR4.1, CR6.1; also elsewhere on the board
/Connectors/Valve1-: CR1.2, Q1.2 (C_1), Q1.4 (C_2); also elsewhere on the board
/Connectors/Valve2-: CR2.2, Q2.2 (C_1), Q2.4 (C_2); also elsewhere on the board
/Connectors/Valve3-: CR3.2, Q3.2 (C_1), Q3.4 (C_2); also elsewhere on the board
/Connectors/Valve4-: CR4.2, Q4.2 (C_1), Q4.4 (C_2); also elsewhere on the board
/Connectors/Valve5-: CR5.2, Q5.2 (C_1), Q5.4 (C_2); also elsewhere on the board
/Connectors/Valve6-: CR6.2, Q6.2 (C_1), Q6.4 (C_2); also elsewhere on the board
/Connectors/Valve7-: CR7.2, Q7.2 (C_1), Q7.4 (C_2); also elsewhere on the board
/Connectors/Valve8-: CR8.2, Q8.2 (C_1), Q8.4 (C_2); also elsewhere on the board
/Connectors/Valve9-: CR9.2, Q9.2 (C_1), Q9.4 (C_2); also elsewhere on the board
/Connectors/Valve10-: CR10.2, Q10.2 (C_1), Q10.4 (C_2); also elsewhere on the board
/Connectors/Valve11-: CR11.2, Q11.2 (C_1), Q11.4 (C_2); also elsewhere on the board
/Connectors/Valve12-: CR12.2, Q12.2 (C_1), Q12.4 (C_2); also elsewhere on the board
/Connectors/Valve13-: CR13.2, Q13.2 (C_1), Q13.4 (C_2); also elsewhere on the board
/Connectors/Valve14-: CR14.2, Q14.2 (C_1), Q14.4 (C_2); also elsewhere on the board
/Connectors/Valve15-: CR15.2, Q15.2 (C_1), Q15.4 (C_2); also elsewhere on the board
/Connectors/Valve16-: CR16.2, Q16.2 (C_1), Q16.4 (C_2); also elsewhere on the board
/Connectors/Valve17-: CR17.2, Q17.2 (C_1), Q17.4 (C_2); also elsewhere on the board
/Connectors/Valve18-: CR18.2, Q18.2 (C_1), Q18.4 (C_2); also elsewhere on the board
/MCU/Valve1: R1.1; also elsewhere on the board
/MCU/Valve2: R2.1, R22.2; also elsewhere on the board
/MCU/Valve3: R3.1; also elsewhere on the board
/MCU/Valve4: R4.1; also elsewhere on the board
/MCU/Valve5: R5.1; also elsewhere on the board
/MCU/Valve6: R6.1; also elsewhere on the board
/MCU/Valve7: R7.1; also elsewhere on the board
/MCU/Valve8: R8.1; also elsewhere on the board
/MCU/Valve9: R9.1; also elsewhere on the board
/MCU/Valve10: R10.1, R25.2; also elsewhere on the board
/MCU/Valve11: R11.1; also elsewhere on the board
/MCU/Valve12: R12.1; also elsewhere on the board
/MCU/Valve13: R13.1; also elsewhere on the board
/MCU/Valve14: R14.1; also elsewhere on the board
/MCU/Valve15: R15.1; also elsewhere on the board
/MCU/Valve16: R16.1; also elsewhere on the board
/MCU/Valve17: R26.2, R30.1; also elsewhere on the board
/MCU/Valve18: R31.1; also elsewhere on the board
unnamed: Q1.1 (B), R1.2
unnamed: Q2.1 (B), R2.2
unnamed: Q3.1 (B), R3.2
unnamed: Q4.1 (B), R4.2
unnamed: Q5.1 (B), R5.2
unnamed: Q6.1 (B), R6.2
unnamed: Q7.1 (B), R7.2
unnamed: Q8.1 (B), R8.2
unnamed: Q9.1 (B), R9.2
unnamed: Q10.1 (B), R10.2
unnamed: Q11.1 (B), R11.2
unnamed: Q12.1 (B), R12.2
unnamed: Q13.1 (B), R13.2
unnamed: Q14.1 (B), R14.2
unnamed: Q15.1 (B), R15.2
unnamed: Q16.1 (B), R16.2
unnamed: Q17.1 (B), R30.2
unnamed: Q18.1 (B), R31.2


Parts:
C1: 0.1u; C_0603_1608Metric
C2, C9, C10, C51, C52: 22u; C_0805_2012Metric
C3: 10uF; C_1206_3216Metric
C4: 8.2n; C_0603_1608Metric
C5: 22p; C_0603_1608Metric
C6: 3.3p; C_0603_1608Metric
C7: 2.2u; C_0603_1608Metric
C8: 100n; C_0603_1608Metric
C53: 15u; C_1206_3216Metric
C54: 1u; C_0603_1608Metric
L1: EXLA1V0402-R82-R; IND_EXLA1V0402-R82-R; PARTREV July 2022; DigiKey_Part_Number 283-EXLA1V0402-R82-RCT-ND
R17: 187k; R_0603_1608Metric
R18: 825k; R_0603_1608Metric
R19: 92k; R_0603_1608Metric
R20: 51.1k; R_0603_1608Metric
R21: 205k; R_0603_1608Metric
R46, R55: 100k; R_0603_1608Metric
R47, R48: 300k; R_0603_1608Metric
U4: TPS61088QRHLRQ1; RHL0020A
U14: WSK06121L000FEA; SMT_121L000FEA_VIS

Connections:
12VA_VA-: C2.2, C3.2, C4.1, C5.2, C6.2, C7.1, C8.2, C9.2, C10.2, C51.2, C52.2, C53.2, C54.2, R19.2, R20.1, R46.1, R55.1, U4.11 (NC), U4.12 (NC), U4.13 (MODE), U4.20 (AGND), U4.21 (PGND), U4.V; also elsewhere on the board
12VB_VA+: R46.2, R47.1; also elsewhere on the board
12VB_VB+: R48.1, R55.2; also elsewhere on the board
+12VB: U14.I2; also elsewhere on the board
/12V Power Supply/EN: U4.2 (EN); also elsewhere on the board
unnamed: C1.2, L1.2, R17.1, U4.4 (SW), U4.5 (SW), U4.6 (SW), U4.7 (SW)
unnamed: C2.1, C3.1, C51.1, C52.1, C53.1, C54.1, R18.1, U4.14 (VOUT), U4.15 (VOUT), U4.16 (VOUT), U14.I1
unnamed: C5.1, R21.2
unnamed: R47.2, U14.E1
unnamed: R48.2, U14.E2
unnamed: C1.1, U4.8 (BOOT)
unnamed: C6.1, R21.1, U4.18 (COMP)
unnamed: R18.2, R19.1, U4.17 (FB)
unnamed: R17.2, U4.3 (FSW)
unnamed: R20.2, U4.19 (ILIM)
unnamed: C4.2, U4.10 (SS)
unnamed: C7.2, U4.1 (VCC)
VBAT: C8.1, C9.1, C10.1, L1.1, U4.9 (VIN); also elsewhere on the board

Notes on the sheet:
TPS61088-Q1 10-A Fully-Integrated Synchronous Boost Converter


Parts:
C46, C47, C61, C63, C70, C71, C72, C73, C74, C76: 0.1u; C_0603_1608Metric
C64, C75: 1u; C_0603_1608Metric
R32, R33, R34, R35, R36, R37, R38, R39: 125; R_0603_1608Metric
R66: 10k; R_0603_1608Metric
U9: AD7124-8BCPZ-RL; CP-32-12_ADI

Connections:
12VA_VA-: C46.1, C47.1, C61.1, C63.1, C64.1, C70.2, C71.2, C72.2, C73.1, C73.2, C74.1, C74.2, C75.1, C75.2, C76.2, R32.1, R33.1, R34.1, R35.1, R36.1, R37.1, R38.1, R39.1, U9.3 (DGND), U9.5 (AIN1/IOUT/VBIAS), U9.7 (AIN3/IOUT/VBIAS/P2), U9.9 (AIN5/IOUT/VBIAS/P4), U9.11 (AIN7/IOUT/VBIAS), U9.13 (REFIN1(-)), U9.15 (AIN9/IOUT/VBIAS), U9.17 (AIN11/IOUT/VBIAS), U9.19 (AIN13/IOUT/VBIAS), U9.21 (AIN15/IOUT/VBIAS/REFIN2(-)), U9.23 (AVSS), U9.33 (EP); also elsewhere on the board
+3V3: C61.2, C63.2, C64.2, C70.1, R66.2, U9.2 (IOVDD), U9.26 (AVDD); also elsewhere on the board
/Connectors/PT: U9.32 (*CS); also elsewhere on the board
/Connectors/SPI2_MISO: U9.28 (DOUT/*RDY); also elsewhere on the board
/Connectors/SPI2_MOSI: U9.29 (DIN); also elsewhere on the board
/Connectors/SPI2_SCK: U9.30 (SCLK); also elsewhere on the board
unnamed: R66.1, U9.27 (*SYNC)
unnamed: C71.1, C72.1, C76.1, U9.12 (REFIN1(+)), U9.22 (REFOUT)
unnamed: C47.2, U9.24 (REGCAPA)
unnamed: C46.2, U9.1 (REGCAPD)
P0REF+: R39.2, U9.4 (AIN0/IOUT/VBIAS); also elsewhere on the board
P1REF+: R32.2, U9.6 (AIN2/IOUT/VBIAS/P1); also elsewhere on the board
P2REF+: R34.2, U9.8 (AIN4/IOUT/VBIAS/P3); also elsewhere on the board
P3REF+: R36.2, U9.10 (AIN6/IOUT/VBIAS); also elsewhere on the board
P4REF+: R37.2, U9.14 (AIN8/IOUT/VBIAS); also elsewhere on the board
P5REF+: R33.2, U9.16 (AIN10/IOUT/VBIAS); also elsewhere on the board
P6REF+: R35.2, U9.18 (AIN12/IOUT/VBIAS); also elsewhere on the board
P7REF+: R38.2, U9.20 (AIN14/IOUT/VBIAS/REFIN2(+)); also elsewhere on the board

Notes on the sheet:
.02 A (20mA max from pressure sensor) * 125 = 2.5 V (2.5 volt max reading from ad7124)


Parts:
J1, J16: 2200980271; Molex_Micro-Lock_2200980271_1x02_P1.25mm_Horizontal
J2: Conn_01x06; PinHeader_1x06_P2.54mm_Vertical
J3, J5: Conn_01x05; PinHeader_1x05_P2.54mm_Vertical
J4: Conn_01x04; PinHeader_1x04_P2.54mm_Vertical
J6, J8, J18, J19, J20, J21, J22, J23, J24: 2200980671; Molex_Micro-Lock_2200980671_1x06_P1.25mm_Horizontal
J7: Conn_01x02; CONN02_534260210_MOL
J13, J14, J15, J25: 2200980471; Molex_Micro-Lock_2200980471_1x04_P1.25mm_Horizontal

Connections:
12VA_VA-: J7.1, J24.2, J24.5, J25.3; also elsewhere on the board
*DRDY: J5.5; also elsewhere on the board
*FAULT: J5.4; also elsewhere on the board
+3V3: J24.1, J25.4; also elsewhere on the board
+12VA: J6.1, J6.3, J6.5, J7.2, J13.1, J13.3, J15.1, J15.3, J18.1, J18.3, J18.5, J19.1, J19.3, J19.5, J20.1, J20.3, J20.5, J21.1, J21.3, J21.5, J22.1, J22.3, J22.5, J23.1, J23.3, J23.5, J24.6; also elsewhere on the board
+12VB: J1.1, J16.1; also elsewhere on the board
/Connectors/*SYNC: J3.5; also elsewhere on the board
/Connectors/ADC: J3.4; also elsewhere on the board
/Connectors/Heater0-: J15.2; also elsewhere on the board
/Connectors/I2C4_SCL: J25.2; also elsewhere on the board
/Connectors/I2C4_SDA: J25.1; also elsewhere on the board
/Connectors/PT: J2.6; also elsewhere on the board
/Connectors/SPI1_MISO: J3.1; also elsewhere on the board
/Connectors/SPI1_MOSI: J3.2; also elsewhere on the board
/Connectors/SPI1_SCK: J3.3; also elsewhere on the board
/Connectors/SPI2_MISO: J5.1; also elsewhere on the board
/Connectors/SPI2_MOSI: J5.2; also elsewhere on the board
/Connectors/SPI2_SCK: J5.3; also elsewhere on the board
/Connectors/T0+: J8.2; also elsewhere on the board
/Connectors/T0-: J8.1; also elsewhere on the board
/Connectors/T1: J2.5; also elsewhere on the board
/Connectors/T1+: J8.4; also elsewhere on the board
/Connectors/T1-: J8.3; also elsewhere on the board
/Connectors/T2: J2.4; also elsewhere on the board
/Connectors/T2+: J8.6; also elsewhere on the board
/Connectors/T2-: J8.5; also elsewhere on the board
/Connectors/T3: J2.3; also elsewhere on the board
/Connectors/T3+: J14.2; also elsewhere on the board
/Connectors/T3-: J14.1; also elsewhere on the board
/Connectors/T4: J2.2; also elsewhere on the board
/Connectors/T4+: J14.4; also elsewhere on the board
/Connectors/T4-: J14.3; also elsewhere on the board
/Connectors/T5: J2.1; also elsewhere on the board
/Connectors/UART_PPU_RX: J4.2, J24.4; also elsewhere on the board
/Connectors/UART_PPU_TX: J4.1, J24.3; also elsewhere on the board
/Connectors/USART3_RX: J4.3; also elsewhere on the board
/Connectors/USART3_TX: J4.4; also elsewhere on the board
/Connectors/Valve1-: J19.2; also elsewhere on the board
/Connectors/Valve2-: J19.4; also elsewhere on the board
/Connectors/Valve3-: J19.6; also elsewhere on the board
/Connectors/Valve4-: J1.2; also elsewhere on the board
/Connectors/Valve5-: J20.2; also elsewhere on the board
/Connectors/Valve6-: J16.2; also elsewhere on the board
/Connectors/Valve7-: J20.4; also elsewhere on the board
/Connectors/Valve8-: J20.6; also elsewhere on the board
/Connectors/Valve9-: J21.2; also elsewhere on the board
/Connectors/Valve10-: J21.4; also elsewhere on the board
/Connectors/Valve11-: J21.6; also elsewhere on the board
/Connectors/Valve12-: J6.2; also elsewhere on the board
/Connectors/Valve13-: J6.4; also elsewhere on the board
/Connectors/Valve14-: J6.6; also elsewhere on the board
/Connectors/Valve15-: J18.2; also elsewhere on the board
/Connectors/Valve16-: J18.4; also elsewhere on the board
/Connectors/Valve17-: J18.6; also elsewhere on the board
/Connectors/Valve18-: J15.4; also elsewhere on the board
P0REF+: J22.2; also elsewhere on the board
P1REF+: J22.4; also elsewhere on the board
P2REF+: J22.6; also elsewhere on the board
P3REF+: J23.2; also elsewhere on the board
P4REF+: J23.4; also elsewhere on the board
P5REF+: J23.6; also elsewhere on the board
P6REF+: J13.2; also elsewhere on the board
P7REF+: J13.4; also elsewhere on the board

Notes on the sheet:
UART Lines
PPU 12V Connector
AD7124-8 Power Connector
SPI Lines
Heater
Chip Select Connector
Valves
Breakouts
MAX31856 Temperature Connector



Board: 4 copper layers, 96.0 x 89.9 mm, 227 parts (57 on the bottom side), 155 nets.

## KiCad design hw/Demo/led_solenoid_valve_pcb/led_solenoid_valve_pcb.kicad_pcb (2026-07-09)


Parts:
D1: LED; LED_0603_1608Metric
J1: Conn_01x02; PinHeader_1x02_P2.54mm_Vertical
R1: 1000; R_0603_1608Metric_Pad0.98x0.95mm_HandSolder

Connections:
unnamed: D1.2 (A), R1.2
unnamed: D1.1 (K), J1.1
unnamed: J1.2, R1.1

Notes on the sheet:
Solenoid LED Connector


Board: 2 copper layers, 7.5 x 8.2 mm, 3 parts (0 on the bottom side), 3 nets.

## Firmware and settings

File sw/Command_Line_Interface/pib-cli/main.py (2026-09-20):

import cmd 
import serial 
import argparse
import struct
import time 


''' INTERNAL COMMANDS '''
CMD_READ_PT1  =  1
CMD_READ_PT2    =  2
CMD_READ_PT3    =  3
CMD_READ_PT4    =  4
CMD_READ_PT5    =  5
CMD_READ_PT6    =  6
CMD_READ_PT7    =  7
CMD_READ_PT8    =  8


# UART Commands for MAX31856 TC Readings

CMD_READ_TC1    =  9
CMD_READ_TC2	= 10
CMD_READ_TC3	= 11
CMD_READ_TC4	= 12
CMD_READ_TC5	= 13

CMD_READ_TC1_CJ = 84
CMD_READ_TC2_CJ = 85
CMD_READ_TC3_CJ = 86
CMD_READ_TC4_CJ = 87
CMD_READ_TC5_CJ = 88


# UART Commands for Solenoid Valves

CMD_OPEN_SOL1  = 14
CMD_OPEN_SOL2  =  15
CMD_OPEN_SOL3  =  17
CMD_OPEN_SOL4  =  18
CMD_OPEN_SOL5  =  19
CMD_OPEN_SOL6  = 20
CMD_OPEN_SOL7  = 21
CMD_OPEN_SOL8  = 22
CMD_OPEN_SOL9  = 23
CMD_OPEN_SOL10  = 24
CMD_OPEN_SOL11  = 25
CMD_OPEN_SOL12  = 26
CMD_OPEN_SOL13  = 27
CMD_OPEN_SOL14  = 28
CMD_OPEN_SOL15  = 29
CMD_OPEN_SOL16  = 30
CMD_OPEN_SOL17  = 31
CMD_OPEN_SOL18  = 32

CMD_CLOSE_SOL1  = 33
CMD_CLOSE_SOL2  = 34
CMD_CLOSE_SOL3   = 35
CMD_CLOSE_SOL4  = 36
CMD_CLOSE_SOL5  = 37
CMD_CLOSE_SOL6  = 38
CMD_CLOSE_SOL7  = 39
CMD_CLOSE_SOL8  = 40
CMD_CLOSE_SOL9  = 41
CMD_CLOSE_SOL10  = 42
CMD_CLOSE_SOL11  = 43
CMD_CLOSE_SOL12  = 44
CMD_CLOSE_SOL13  = 45
CMD_CLOSE_SOL14  = 46
CMD_CLOSE_SOL15  = 47
CMD_CLOSE_SOL16  = 48
CMD_CLOSE_SOL17  = 49
CMD_CLOSE_SOL18  = 50

CMD_READ_VALVE_STATE_1 = 91
CMD_READ_VALVE_STATE_2 = 92
CMD_READ_VALVE_STATE_3 = 93
CMD_READ_VALVE_STATE_4 = 94
CMD_READ_VALVE_STATE_5 = 95
CMD_READ_VALVE_STATE_6 = 96
CMD_READ_VALVE_STATE_7 = 97
CMD_READ_VALVE_STATE_8 = 98
CMD_READ_VALVE_STATE_9 = 99
CMD_READ_VALVE_STATE_10 = 100
CMD_READ_VALVE_STATE_11 = 101
CMD_READ_VALVE_STATE_12 = 102
CMD_READ_VALVE_STATE_13 = 103
CMD_READ_VALVE_STATE_14 = 104
CMD_READ_VALVE_STATE_15 = 105
CMD_READ_VALVE_STATE_16 = 106
CMD_READ_VALVE_STATE_17 = 107 
CMD_READ_VALVE_STATE_18 = 108


# UART Commands for ADC7124 PC104 Stack Readings

CMD_READ_12VA_VB  = 51
CMD_READ_12VA_VA  = 52 # powers all Valves except for 4,6 (which are pwm)
CMD_READ_3V3_VB  = 53
CMD_READ_3V3_VA  = 54
CMD_READ_VBAT_VA  = 66
CMD_READ_VBAT_VB  = 67
CMD_READ_12VB_VA  = 68
CMD_READ_12VB_VB  = 69

CMD_READ_12VA_VB_CURRENT  = 70
CMD_READ_12VA_VA_CURRENT  = 71 
CMD_READ_3V3_VB_CURRENT  = 72
CMD_READ_3V3_VA_CURRENT  = 73
CMD_READ_VBAT_VA_CURRENT  = 74
CMD_READ_VBAT_VB_CURRENT  = 75
CMD_READ_12VB_VA_CURRENT  = 76
CMD_READ_12VB_VB_CURRENT  = 77

# UART Commands for FDC2214

CMD_READ_CAPACITANCE_A1  = 55
CMD_READ_CAPACITANCE_A2  = 56
CMD_READ_CATALYST_LEVEL_A1  = 57
CMD_READ_CATALYST_LEVEL_A2  = 58


# UART Command for heater

CMD_HEAT_CATALYST  = 59

CMD_MANUAL_HEATER_TURN_ON = 89
CMD_MANUAL_HEATER_TURN_OFF = 90


# UART Commands for Pressure Regulation (PWM / PID)

CMD_REGULATE_PRESSURE_INPUT_VALUE  = 60
CMD_REGULATE_PRESSURE_2_INPUT_VALUE  = 61


# UART Commands for PPU Control (OBC -> PIB)

CMD_PPU_CURRENT_READ_1  = 62
CMD_PPU_CURRENT_READ_2  = 63
CMD_PPU_ON  = 64
CMD_PPU_OFF  = 65

CMD_TOGGLE_RED_LED = 78
CMD_TOGGLE_GREEN_LED = 79
CMD_TOGGLE_AMBER_LED = 80


# Read Device IDs 

CMD_READ_ID_PT = 81
CMD_READ_ID_V = 82
CMD_READ_ID_FDC = 83 







class SerialLink: # https://docs.python.org/3/tutorial/classes.html 

# "When a class defines an __init__() method, class instantiation automatically invokes __init__() for the newly created class instance. So in this example, a new, initialized instance can be obtained by"

    """Computer to Arduino Link """
 
    def __init__(self, port: str, baud: int = 115200, timeout: float = 4.0):
        self.port = port
        self.baud = baud
        self.timeout = timeout
        self.conn: serial.Serial | None = None # written like this so that the type checker knows that self.conn is either a serial.Serial object or None.
 
    def open(self):
        self.conn = serial.Serial(self.port, self.baud, timeout=self.timeout) # https://pyserial.readthedocs.io/en/latest/pyserial_api.html << creating the serial connection and assigining it to the self.conn variable.
  
 
    def close(self):
        if self.conn:
            self.conn.close()
 
    def send_command(self, code: int, arg: int = 0x00):
        if not 0 <= code <= 255:
            raise ValueError(f"Command code out of range for 1 byte: {code}")
        if not 0 <= arg <= 255:
            raise ValueError(f"Argument out of range: {arg}")
        payload = struct.pack("BB", code, arg)  # always 2 bytes // 
        self.conn.write(payload) # sends the bit value // 

    def read_response(self, terminator: bytes = b'\n') -> str:
        """Read a line of text response from the device."""
        self.conn.reset_input_buffer()  # discard any stale responses
        time.sleep(0.05)          # let STM32 start responding
        
        if not self.conn:
            return ""

        line = self.conn.readline()  # blocks until terminator or timeout
        return line.decode('utf-8', errors='replace').strip()

 

class PIBShell(cmd.Cmd): # https://realpython.com/ref/stdlib/cmd/ 
    intro = "Welcome to the PIB shell. Use with an arduino to command the payload interface board of MonARCH. Type help or ? to list commands.\n"
    prompt = "(pib) "

    def __init__(self, pib: SerialLink):
        super().__init__()
        self.pib = pib

    def do_greet(self, arg):
        """Greet the user."""
        print(f"Hello, {arg}!")

    def do_exit(self, arg):
        """Exit the shell."""
        print("Exiting the PIB shell.")
        return True

    def do_toggle_red_led(self, arg):
        """Toggling the RED LED on the payload interface board."""
        print("Toggling LED...")
        self.pib.send_command(CMD_TOGGLE_RED_LED)  

    def do_toggle_green_led(self, arg):
        """Toggling the GREEN LED on the payload interface board."""
        print("Toggling LED...")
        self.pib.send_command(CMD_TOGGLE_GREEN_LED)

    def do_toggle_amber_led(self, arg):
        """Toggling the GREEN LED on the payload interface board."""
        print("Toggling LED...")
        self.pib.send_command(CMD_TOGGLE_AMBER_LED)

    def do_open_valve(self, arg):
        """Open the valve on the payload interface board."""
        try: 
            valve = int(arg)
        except ValueError:
            print("Invalid input. Please enter a number between 1 and 18.")
            return

        if(valve < 1 or valve > 18):
            print("Invalid valve number. Please enter a number between 1 and 18.")
            return
        else:
            print("Opening valve " + arg + "...")
            self.pib.send_command(CMD_OPEN_SOL1 + (valve-1)) # takes valve 1 and adds the valve number to obtain the correct command.
            
      
    def do_close_valve(self, arg):
        """Close the valve on the payload interface board."""
        try: 
            valve = int(arg)
        except ValueError:
            print("Invalid input. Please enter a number between 1 and 18.")
            return

        if(valve < 1 or valve > 18):
            print("Invalid valve number. Please enter a number between 1 and 18.")
            return
        else:
            print("Closing valve " + arg + "...")
            self.pib.send_command(CMD_CLOSE_SOL1 + (valve-1)) # takes valve 1 and adds the valve number to obtain the correct command.
    def do_read_cj_temp(self,arg):
        """Read the cold junction temperature from the payload interface board."""
        try: 
            sensor = int(arg)
        except ValueError:
            print("Invalid input. Please enter a number between 1 and 5.")
            return

        if(sensor < 1 or sensor > 5):
            print("Invalid sensor number. Please enter a number between 1 and 5.")
            return
        else:
            print("Reading cold junction temperature from sensor " + arg + "...")
            self.pib.send_command(CMD_READ_TC1_CJ + (sensor - 1)) # takes sensor 1 and adds the sensor number - 1 to obtain the correct command.
            response = self.pib.read_response()
            if response:
                print(f"PIB says: {response}")

    def do_read_temp(self, arg):
        """Read the temperature from the payload interface board."""
        try: 
            sensor = int(arg)
        except ValueError:
            print("Invalid input. Please enter a number between 1 and 5.")
            return

        if(sensor < 1 or sensor > 5):
            print("Invalid sensor number. Please enter a number between 1 and 5.")
            return
        else:
            print("Reading temperature from sensor " + arg + "...")
            self.pib.send_command(CMD_READ_TC1 + (sensor - 1)) # takes sensor 1 and adds the sensor number - 1 to obtain the correct command.
            response = self.pib.read_response()
            if response:
                print(f"PIB says: {response}" + " Celcius degrees")

    def do_read_pressure(self, arg):
        """Read the pressure from the payload interface board."""
        try: 
            sensor = int(arg)
        except ValueError:
            print("Invalid input. Please enter a number between 1 and 8.")
            return

        if(sensor < 1 or sensor > 8):
            print("Invalid sensor number. Please enter a number between 1 and 8.")
            return
        else:
            print("Reading pressure from sensor " + arg + "...")
            self.pib.send_command(CMD_READ_PT1 + (sensor - 1)) # takes sensor 1 and adds the sensor number - 1 to obtain the correct command.
            response = self.pib.read_response()
            if response:
                print(f"PIB says: {response}" + " Pa") 

    def do_read_capacitancez(self, arg):
        """Read the capacitance chip from the payload interface board."""
        print("Reading pressure from sensor " + arg + "...")

        try: 
            sensor = int(arg)
        except ValueError:
            print("Invalid input. Please enter a number between 1 and 2.")
            return 
        
        self.pib.send_command(CMD_READ_PT1 + (sensor - 1)) # takes sensor 1 and adds the sensor number - 1 to obtain the correct command.
        response = self.pib.read_response()
        if response:
            print(f"PIB says: {response}" + " Pa") 

    def do_read_level(self, arg):
        """Read the level of the FAM142 propellant from the payload interface board."""
        print("Reading propellant level from sensor " + arg + "...")


    def do_read_valve_state(self, arg):
        """Read the valve state on the payload interface board."""
        try: 
            valve = int(arg)
        except ValueError:
            print("Invalid input. Please enter a number between 1 and 18.")
            return

        if(valve < 1 or valve > 18):
            print("Invalid valve number. Please enter a number between 1 and 18.")
            return
        else:
            print("Reading valve " + arg + "...")
            self.pib.send_command(CMD_READ_VALVE_STATE_1 + (valve - 1)) # takes valve 1 and adds the valve number - 1 to obtain the correct command.
            response = self.pib.read_response()
            if response:
                print(f"PIB says: {response}")

    def do_read_3v3(self, arg):
        """Read 3v3 Bus of the PIB"""
        try: 
            value = int(arg)

        except ValueError:
            print("Invalid input. Please enter a number between 1 and 2.")
            return

        if(value <1 or value > 2):
            print("Invalid voltage divider number. Please enter either 1 or 2.")
            return
        else:
            print("Reading voltage divider " + arg + "...")
            self.pib.send_command(CMD_READ_3V3_VB + (value - 1)) 
            response = self.pib.read_response()
            if response:
                print(f"PIB says: {response}" + " Volts") 

    def do_read_VBAT(self,arg):
        """Read VBAT Bus of the PIB"""
        try: 
            value = int(arg)
        except ValueError:
            print("Invalid input. Please enter a number between 1 and 2.")
            return
        if(value <1 or value > 2):
            print("Invalid voltage divider number. Please enter either 1 or 2.")
            return
        else:
            print("Reading voltage divider " + arg + "...")
            self.pib.send_command(CMD_READ_VBAT_VA + (value - 1)) 
            response = self.pib.read_response()
            if response:
                print(f"PIB says: {response}" + " Volts") 

    def do_read_12VB(self, arg):
        """Read 12V Bus of the PIB"""
        try: 
            value = int(arg)
        except ValueError:
            print("Invalid input. Please enter a number between 1 and 2.")
            return
        if(value <1 or value > 2):
            print("Invalid voltage divider number. Please enter either 1 or 2.")
            return
        else:
            print("Reading voltage divider " + arg + "...")
            self.pib.send_command(CMD_READ_12VB_VA + (value - 1)) 
            response = self.pib.read_response()
            if response:
                print(f"PIB says: {response}" + " Volts") 
    def do_read_12VA(self, arg):
        """Read 12V Bus of the PIB"""
        try: 
            value = int(arg)
        except ValueError:
            print("Invalid input. Please enter a number between 1 and 2.")
            return
        if(value <1 or value > 2):
            print("Invalid voltage divider number. Please enter either 1 or 2.")
            return
        else:
            print("Reading voltage divider " + arg + "...")
            self.pib.send_command(CMD_READ_12VA_VB + (value - 1)) 
            response = self.pib.read_response()
            if response:
                print(f"PIB says: {response}" + " Volts") 


    def do_read_3v3_current(self, arg):
        """Read 3v3 current of the PIB"""
        try: 
            value = int(arg)

        except ValueError:
            print("Invalid input. Please enter a number between 1 and 2.")
            return

        if(value <1 or value > 2):
            print("Invalid voltage divider number. Please enter either 1 or 2.")
            return
        else:
            print("Reading voltage divider current" + arg + "...")
            self.pib.send_command(CMD_READ_3V3_VB_CURRENT + (value - 1)) 
            response = self.pib.read_response()
            if response:
                print(f"PIB says: {response}" + " Milli-Amps") 

    def do_read_VBAT_current(self,arg):
        """Read VBAT Currnet of the PIB"""
        try: 
            value = int(arg)
        except ValueError:
            print("Invalid input. Please enter a number between 1 and 2.")
            return
        if(value <1 or value > 2):
            print("Invalid voltage divider number. Please enter either 1 or 2.")
            return
        else:
            print("Reading voltage divider current " + arg + "...")
            self.pib.send_command(CMD_READ_VBAT_VA_CURRENT + (value - 1)) 
            response = self.pib.read_response()
            if response:
                print(f"PIB says: {response}" + " Milli-Amps") 

    def do_read_12VB(self, arg):
        """Read 12V Current of the PIB"""
        try: 
            value = int(arg)
        except ValueError:
            print("Invalid input. Please enter a number between 1 and 2.")
            return
        if(value <1 or value > 2):
            print("Invalid voltage divider number. Please enter either 1 or 2.")
            return
        else:
            print("Reading voltage divider current" + arg + "...")
            self.pib.send_command(CMD_READ_12VB_VA_CURRENT + (value - 1)) 
            response = self.pib.read_response()
            if response:
                print(f"PIB says: {response}" + " Milli-Amps") 
    def do_read_12VA(self, arg):
        """Read 12V Current of the PIB"""
        try: 
            value = int(arg)
        except ValueError:
            print("Invalid input. Please enter a number between 1 and 2.")
            return
        if(value <1 or value > 2):
            print("Invalid voltage divider number. Please enter either 1 or 2.")
            return
        else:
            print("Reading voltage divider current" + arg + "...")
            self.pib.send_command(CMD_READ_12VA_VB_CURRENT + (value - 1)) 
            response = self.pib.read_response()
            if response:
                print(f"PIB says: {response}" + " Milli-Amps") 


    def do_read_id(self, arg):
        """Read Device ID"""
        if(arg == "PT"):
            print("Reading Pressure AD7124 Device ID")

            self.pib.send_command(CMD_READ_ID_PT)
            response = self.pib.read_response()
            if response:
                print(f"PIB Says: {response}")
        
        elif(arg == "V"):
            print("Reading Voltage AD7124 Device ID")

            self.pib.send_command(CMD_READ_ID_V)
            response = self.pib.read_response()
            if response:
                print(f"PIB Says: {response}")

        elif(arg == "FDC"):
            print("Reading Capacitance Chip Device ID")

            self.pib.send_command(CMD_READ_ID_FDC)
            response = self.pib.read_response()
            if response:
                print(f"PIB Says: {response}")




        # parameterized command
    def do_set_duty_1(self, args):
        '''Set the duty cycle for the pressure regulation on the payload interface board.'''

        try: 
            duty = int(args)
        except ValueError:
            print("Invalid input. Please enter a number between 1 and 2.")
            return 

        if(duty < 0 or duty > 100):
            print("Invalid duty cycle. Please enter a number between 0 and 100.")
            return

        self.pib.send_command(CMD_REGULATE_PRESSURE_INPUT_VALUE, duty)


    def do_set_duty_2(self, args):
        '''Set the duty cycle for the pressure regulation on the payload interface board.'''

        try: 
            duty = int(args)
        except ValueError:
            print("Invalid input. Please enter a number between 1 and 2.")
            return 

        if(duty < 0 or duty > 100):
            print("Invalid duty cycle. Please enter a number between 0 and 100.")
            return

        self.pib.send_command(CMD_REGULATE_PRESSURE_2_INPUT_VALUE, duty)


    def do_run_sequence(self, args):
        """Run a predefined sequence on the payload interface board."""
        
        print(arg)

        if(arg == "fill_accum1"):
            print("Running fill accumulator sequence 1...")
            # Here add the code to run sequence 1 on the PIB

        if(arg == "run_espray"):
            print("Running e-spray sequence...")

        # Here add the code to open the valve on the PIB

    def do_help(self, arg):
        """List available commands with "help" or detailed help with "help cmd"."""
        super().do_help(arg) 


def parse_args(): # Parse command-line arguments when running the script directly. This allows the user to specify the serial port and baud rate for the Arduino connection.
    parser = argparse.ArgumentParser(description="PIB command-line interface")
    parser.add_argument(
        "--port",
        default="COM12",
        help="Serial port the Arduino is connected to (default: %(default)s)",
    )
    parser.add_argument(
        "--baud",
        type=int,
        default=115200,
        help="Baud rate for the serial link (default: %(default)s)",
    )
    return parser.parse_args()


if __name__ == "__main__": # https://realpython.com/ref/stdlib/cmd/ 
    args = parse_args()
    link = SerialLink(port=args.port, baud=args.baud) # instantiate the class. 
    link.open()
    try:
        PIBShell(link).cmdloop() # https://docs.python.org/3/library/cmd.html cmd loop 
    finally:
        link.close()

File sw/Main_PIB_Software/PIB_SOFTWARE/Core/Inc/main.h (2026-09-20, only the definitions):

#define T4_EN_Pin GPIO_PIN_2
#define T4_EN_GPIO_Port GPIOE
#define T2_EN_Pin GPIO_PIN_3
#define T2_EN_GPIO_Port GPIOE
#define PT_EN_Pin GPIO_PIN_4
#define PT_EN_GPIO_Port GPIOE
#define TIM3_CH3_VALVE6_Pin GPIO_PIN_5
#define TIM3_CH3_VALVE6_GPIO_Port GPIOE
#define POW12_EN_Pin GPIO_PIN_0
#define POW12_EN_GPIO_Port GPIOH
#define UART4_TX_PPU_Pin GPIO_PIN_0
#define UART4_TX_PPU_GPIO_Port GPIOA
#define UART4_RX_PPU_Pin GPIO_PIN_1
#define UART4_RX_PPU_GPIO_Port GPIOA
#define ADC_EN_Pin GPIO_PIN_4
#define ADC_EN_GPIO_Port GPIOA
#define SPI1_SCK_BAT_Pin GPIO_PIN_5
#define SPI1_SCK_BAT_GPIO_Port GPIOA
#define SPI1_MISO_BAT_Pin GPIO_PIN_6
#define SPI1_MISO_BAT_GPIO_Port GPIOA
#define SPI1_MOSI_BAT_Pin GPIO_PIN_7
#define SPI1_MOSI_BAT_GPIO_Port GPIOA
#define USART3_TX_OBC_Pin GPIO_PIN_4
#define USART3_TX_OBC_GPIO_Port GPIOC
#define USART3_RX_OBC_Pin GPIO_PIN_5
#define USART3_RX_OBC_GPIO_Port GPIOC
#define LED_PIN_AMBER_Pin GPIO_PIN_13
#define LED_PIN_AMBER_GPIO_Port GPIOE
#define LED_PIN_GREEN_Pin GPIO_PIN_14
#define LED_PIN_GREEN_GPIO_Port GPIOE
#define LED_PIN_RED_Pin GPIO_PIN_15
#define LED_PIN_RED_GPIO_Port GPIOE
#define I2C4_SCL_BREAKOUT_Pin GPIO_PIN_10
#define I2C4_SCL_BREAKOUT_GPIO_Port GPIOB
#define I2C4_SDA_BREAKOUT_Pin GPIO_PIN_11
#define I2C4_SDA_BREAKOUT_GPIO_Port GPIOB
#define valve1_Pin GPIO_PIN_12
#define valve1_GPIO_Port GPIOB
#define valve2_Pin GPIO_PIN_13
#define valve2_GPIO_Port GPIOB
#define valve3_Pin GPIO_PIN_14
#define valve3_GPIO_Port GPIOB
#define valve5_Pin GPIO_PIN_15
#define valve5_GPIO_Port GPIOB
#define valve7_Pin GPIO_PIN_8
#define valve7_GPIO_Port GPIOD
#define valve8_Pin GPIO_PIN_9
#define valve8_GPIO_Port GPIOD
#define TIM8_CH1_VALVE4_Pin GPIO_PIN_6
#define TIM8_CH1_VALVE4_GPIO_Port GPIOC
#define valve9_Pin GPIO_PIN_7
#define valve9_GPIO_Port GPIOC
#define valve10_Pin GPIO_PIN_8
#define valve10_GPIO_Port GPIOC
#define valve11_Pin GPIO_PIN_9
#define valve11_GPIO_Port GPIOC
#define valve12_Pin GPIO_PIN_8
#define valve12_GPIO_Port GPIOA
#define heater_en_Pin GPIO_PIN_10
#define heater_en_GPIO_Port GPIOA
#define valve18_Pin GPIO_PIN_11
#define valve18_GPIO_Port GPIOA
#define valve13_Pin GPIO_PIN_10
#define valve13_GPIO_Port GPIOC
#define valve14_Pin GPIO_PIN_11
#define valve14_GPIO_Port GPIOC
#define valve16_Pin GPIO_PIN_12
#define valve16_GPIO_Port GPIOC
#define valve17_Pin GPIO_PIN_0
#define valve17_GPIO_Port GPIOD
#define TC_SPI2_SCK_Pin GPIO_PIN_1
#define TC_SPI2_SCK_GPIO_Port GPIOD
#define valve15_Pin GPIO_PIN_2
#define valve15_GPIO_Port GPIOD
#define TC_SPI2_MISO_Pin GPIO_PIN_3
#define TC_SPI2_MISO_GPIO_Port GPIOD
#define TC_SPI2_MOSI_Pin GPIO_PIN_4
#define TC_SPI2_MOSI_GPIO_Port GPIOD
#define T1_EN_Pin GPIO_PIN_9
#define T1_EN_GPIO_Port GPIOB
#define T3_EN_Pin GPIO_PIN_0
#define T3_EN_GPIO_Port GPIOE
#define T5_EN_Pin GPIO_PIN_1
#define T5_EN_GPIO_Port GPIOE
#define LOW_PRESSURE_RANGE 0
#define HIGH_PRESSURE_RANGE 40 // MPa|| CHANGE once yk the pressure range of pressure transducer
#define HIGH_CURRENT_PRESSURE 20 // (mA)
#define LOW_CURRENT_PRESSURE 4 // (mA)

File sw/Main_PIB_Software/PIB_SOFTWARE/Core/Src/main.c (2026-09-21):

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
/* Includes ------------------------------------------------------------------*/
#include "main.h"
#include "cmsis_os.h"
#include "i2c.h"
#include "spi.h"
#include "tim.h"
#include "usart.h"
#include "gpio.h"

/* USER CODE BEGIN Includes */


/* Native FreeRTOS — needed for ISR-safe functions */
#include "FreeRTOS.h"
#include "semphr.h"


extern osSemaphoreId_t s_rx_semaphoreHandle;


// ----------------- Sensor Includes -----------------------

#include "ad7124_console_app.h"
#include "ad7124.h"
#include "max31856.h"
#include "fdc2214.h"

// Serial Interface For Debugging || Serial wire JTAG debug port (SWJ-DP)
#include <stdio.h>


// Include main struct 

#include "systems.h"





/* USER CODE END Includes */


/* USER CODE BEGIN PV */

int32_t setupResult;
uint32_t device_id;
uint8_t rx_cmd[2]; // single byte for all UART commands. second byte for arguments if needed. (e.g. for setting pressure value) 
uint8_t rx_cmd_copy[2];  // task reads from here — declare this globally

uint8_t tx_cmd[1];
char uart_buffer[64]; // used for sending data across uart3
float temperature;
float value;
uint8_t duty_cycle;
GPIO_PinState pinState;


struct system_flags payload_flags = {
	.exceed_pressure_flag = false,
	.exceed_temp_flag = false
};

struct error_flags error_flags = {

};

struct Data_Log data_payload_packet;

Payload_System Payload_Sys = {
	.fsm_state = STATE_BOOT,
	.sys_flags = payload_flags,
	.err_flags = error_flags,
	.data_log = data_payload_packet

};





// chip struct defines to be able to extern them.
max31856_t max31856T1 = {
    .spi_handle = &hspi2,
    .cs_pin = { .gpio_port = T1_EN_GPIO_Port, .gpio_pin = T1_EN_Pin }
};

max31856_t max31856T2 = {
    .spi_handle = &hspi2,
    .cs_pin = { .gpio_port = T2_EN_GPIO_Port, .gpio_pin = T2_EN_Pin }
};

max31856_t max31856T3 = {
    .spi_handle = &hspi2,
    .cs_pin = { .gpio_port = T3_EN_GPIO_Port, .gpio_pin = T3_EN_Pin }
};

max31856_t max31856T4 = {
    .spi_handle = &hspi2,
    .cs_pin = { .gpio_port = T4_EN_GPIO_Port, .gpio_pin = T4_EN_Pin }
};

max31856_t max31856T5 = {
    .spi_handle = &hspi2,
    .cs_pin = { .gpio_port = T5_EN_GPIO_Port, .gpio_pin = T5_EN_Pin }
};




/* USER CODE END PV */

void SystemClock_Config(void);
void MX_FREERTOS_Init(void);
/* USER CODE BEGIN 0 */

// struct max31856_t *max31856;


/* USER CODE END 0 */

/**
  * @brief  The application entry point.
  * @retval int
  */
int main(void)
{

  /* MCU Configuration--------------------------------------------------------*/

  /* Reset of all peripherals, Initializes the Flash interface and the Systick. */
  HAL_Init();

  /* Configure the system clock */
  SystemClock_Config();

  /* USER CODE BEGIN SysInit */

//  GPIO_Driver_Init(&LED_BLINK);


  /* USER CODE END SysInit */

  /* Initialize all configured peripherals */
  MX_GPIO_Init();
  MX_I2C4_Init();
  MX_SPI1_Init();
  MX_SPI2_Init();
  MX_UART4_Init();
  MX_USART3_UART_Init();
  MX_TIM8_Init();
  MX_TIM3_Init();
  /* USER CODE BEGIN 2 */

//  HAL_GPIO_WritePin(LED_PIN_RED_GPIO_Port, LED_PIN_RED_Pin, GPIO_PIN_SET);


  // blocking no work
//  HAL_UART_Receive(&huart3, rx_cmd, 1,0xFFFF);
//  HAL_UART_Transmit(&huart3, rx_cmd, 1, 0xFFFF);

  // start receiving UART commands.

  HAL_UART_Receive_IT(&huart3, rx_cmd, 2);


// DEACTIVATE ALL SPI2 ICs

// (NOT CS) So if a pin is pulled low the chip will be selected.


  // SPI 2 BUS
  HAL_GPIO_WritePin(T1_EN_GPIO_Port, T1_EN_Pin, GPIO_PIN_SET);
  HAL_GPIO_WritePin(T2_EN_GPIO_Port, T2_EN_Pin, GPIO_PIN_SET);
  HAL_GPIO_WritePin(T3_EN_GPIO_Port, T3_EN_Pin, GPIO_PIN_SET);
  HAL_GPIO_WritePin(T4_EN_GPIO_Port, T4_EN_Pin, GPIO_PIN_SET);
  HAL_GPIO_WritePin(T5_EN_GPIO_Port, T5_EN_Pin, GPIO_PIN_SET);
  HAL_GPIO_WritePin(PT_EN_GPIO_Port, PT_EN_Pin, GPIO_PIN_SET);
  // SPI 1 BUS

  HAL_GPIO_WritePin(ADC_EN_GPIO_Port, ADC_EN_Pin, GPIO_PIN_SET);

 // create a setup function for all sensors and turn red_led if fails to setup / read from device id's of all sensors

    // RED = MAX31856 Fail
    // AMBER = ADC2214 Voltage 
    // AMBER + GREEN = ADC2214 Pressure
    // RED + AMBER = FDC2214
    // Green = Everything Setup Correctly

// ------------------ SET-UP SENSORS -------------------- \\

// ADC7124 || PT Readings Init

  /* Initialize the AD7124 application before the FreeRTOS takes over  */

    // this setup will be for POWER
    // added param for cs -> CS = 0 = AD7124 VOLTAGE      |
    				//       CS = 1 = AD7124 PRESSURE   | for measuring

// Setup pressure ADC

    if ((setupResult = ad7124_app_initialize(AD7124_CONFIG_A,PRESSURE)) < 0) {
  		// Handle error setting up AD7124 here
  	  printf("Failed to init ad7124 pressure \n");
  	  HAL_GPIO_WritePin(LED_PIN_AMBER_GPIO_Port, LED_PIN_AMBER_Pin, GPIO_PIN_SET);
      HAL_GPIO_WritePin(LED_PIN_GREEN_GPIO_Port, LED_PIN_GREEN_Pin, GPIO_PIN_RESET);
    }
    printf("Setup Pressure Result: %ld", setupResult);

// Setup Voltage ADC

    if ((setupResult = ad7124_app_initialize(AD7124_CONFIG_A,VOLTAGE)) < 0) {
  		// Handle error setting up AD7124 here
  	  printf("Failed to init ad7124 voltage \n");
  	  HAL_GPIO_WritePin(LED_PIN_AMBER_GPIO_Port, LED_PIN_AMBER_Pin, GPIO_PIN_SET);

    }

    printf("Setup voltage Result: %ld", setupResult);


// MAX31856 Setup || Temperature Reading K-Type Thermocouples Readings INIT

// T1

   	max31856_init(&max31856T1);

   	max31856_set_noise_filter(&max31856T1, CR0_FILTER_OUT_60Hz); // Noise filter is for filtering out EMI in very long wires
   	max31856_set_cold_junction_enable(&max31856T1, CR0_CJ_ENABLED); // External Sensor which measures the cold junction and references
   	max31856_set_thermocouple_type(&max31856T1, CR1_TC_TYPE_K); // K - type thermocouple
   	max31856_set_average_samples(&max31856T1, CR1_AVG_TC_SAMPLES_2);
   	max31856_set_open_circuit_fault_detection(&max31856T1, CR0_OC_DETECT_ENABLED_TC_LESS_2ms);
   	max31856_set_conversion_mode(&max31856T1, CR0_CONV_CONTINUOUS);


//   T2

 	max31856_init(&max31856T2);

   	max31856_set_noise_filter(&max31856T2, CR0_FILTER_OUT_60Hz);
   	max31856_set_cold_junction_enable(&max31856T2, CR0_CJ_ENABLED); // External Sensor which measures the cold junction and references
   	max31856_set_thermocouple_type(&max31856T2, CR1_TC_TYPE_K); // K - type thermocouple
   	max31856_set_average_samples(&max31856T2, CR1_AVG_TC_SAMPLES_2);
   	max31856_set_open_circuit_fault_detection(&max31856T2, CR0_OC_DETECT_ENABLED_TC_LESS_2ms);
   	max31856_set_conversion_mode(&max31856T2, CR0_CONV_CONTINUOUS); // continous mode for testing


//   T3

 	max31856_init(&max31856T3);

   	max31856_set_noise_filter(&max31856T3, CR0_FILTER_OUT_60Hz);
   	max31856_set_cold_junction_enable(&max31856T3, CR0_CJ_ENABLED);
   	max31856_set_thermocouple_type(&max31856T3, CR1_TC_TYPE_K);
   	max31856_set_average_samples(&max31856T3, CR1_AVG_TC_SAMPLES_2);
   	max31856_set_open_circuit_fault_detection(&max31856T3, CR0_OC_DETECT_ENABLED_TC_LESS_2ms);
   	max31856_set_conversion_mode(&max31856T3, CR0_CONV_CONTINUOUS);
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

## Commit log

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2026-02-21 First Commit- Breakout Board + Software Setup
    [monarch_breakout_board_rev1.kicad_pcb, monarch_breakout_board_rev1.kicad_sch]
2026-02-22 Components selection for valves so far
    [1SMA4757.step, 35SVT82M.step, EDI2CAP.CFG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]
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2026-02-24 Official PIB Code + FDC2214 Driver
    [RGH0016A.stp]
2026-02-24 Added FDC2214 + INA-226-Q1 to schematic
    [DGS0010A.stp, RGH0016A.stp, monarch_breakout_board_rev1.kicad_sch]
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2026-02-26 FDC2214 LC Tank Work
    [monarch_breakout_board_rev1.kicad_sch]
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2026-02-27 Schematic Work + Cleanup + Initial PCB Design
    [5037630491.stp, monarch_breakout_board_rev1.kicad_pcb, monarch_breakout_board_rev1.kicad_sch]
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2026-02-28 Footprints, Connectors, and Routing
    [5037630291.stp, monarch_breakout_board_rev1.kicad_pcb, monarch_breakout_board_rev1.kicad_sch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]
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2026-03-02 PIB Layout Update 3/2
    [monarch_payload_interface_board_rev1.kicad_pcb, thermocouples.kicad_sch]
2026-03-03 40 Mhz Clock Work + Test Software for Main Control Flow on Dev Board
    [monarch_breakout_board_rev1.kicad_sch]
2026-03-04 Crystal Clock Completion, All Pins Assigned, More Routing Work
    [monarch_breakout_board_rev1.kicad_pcb, monarch_breakout_board_rev1.kicad_sch, untitled.kicad_sch]
2026-03-04 Revert "Crystal Clock Completion, All Pins Assigned, More Routing Work"
    This reverts commit 432819c756e1f3cf9abb2627b488983cb7a3cfe3
    [monarch_breakout_board_rev1.kicad_pcb, monarch_breakout_board_rev1.kicad_sch, untitled.kicad_sch]
2026-03-04 Breakout Board History Fix
    [monarch_breakout_board_rev1.kicad_pcb, monarch_breakout_board_rev1.kicad_sch, untitled.kicad_sch]
2026-03-05 SOFTWARE FIX + More sensor drivers (IN PROGRESS) -> Need to work on integration with stm32l4a6
    [Dev_Code_STM32H745ZI-Q.ioc, ad7124.h, max31856.c]
2026-03-06 Amplifier Initial Setup / Routing Work
    [DBV0005A.stp, monarch_breakout_board_rev1.kicad_pcb, monarch_breakout_board_rev1.kicad_sch]
2026-03-06 PIB Progress
    Most MCU pins selected. more to come.
    [heater.kicad_sch]
2026-03-07 Deletion of Components -> Ammeter Circuit Scraped + External 40 MHz Clock + Pull Up Pins on I2C
    [monarch_breakout_board_rev1.kicad_pcb, monarch_breakout_board_rev1.kicad_sch]
2026-03-08 PIB layout update
    done pending Ben O approval
    [20021121-00008C4LF.step, EXLA.prt, EXLA.stp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]
2026-03-08 Final Breakout Board Work
    [monarch_breakout_board_rev1.kicad_pcb, monarch_breakout_board_rev1.kicad_sch, untitled.kicad_sch]
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2026-03-09 PIB minor updates & radio board
    [543630689.stp, MCU.kicad_sch, Radio_Board.kicad_pcb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]
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2026-03-10 FIXES after Review
    [monarch_breakout_board_rev1.csv, monarch_breakout_board_rev1.kicad_pcb, monarch_breakout_board_rev1.kicad_sch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]
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2026-03-10 FIXES V2
    [monarch_breakout_board_rev1.kicad_pcb, monarch_breakout_board_rev1.kicad_sch]
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2026-03-10 fixed vias
    [monarch_payload_interface_board_rev1.kicad_pcb]
2026-03-11 Changes V3 -> Fixed I2C Line Lengths, Fixed Connection, and RAN DRC w/ no issues, and changed the fill to solid
    [monarch_breakout_board_rev1.kicad_pcb]
2026-03-12 I2C lengths breakout board
    [monarch_breakout_board_rev1.kicad_pcb]
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2026-06-30 BOOT PIN FIX + NRST PIN FIX
    [MCU.kicad_sch, PC104_stack.kicad_sch, connectors.kicad_sch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]
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2026-06-30 Debugging LEDS, Power LEDs, and Button for NRST
    [MCU.kicad_sch, PC104_stack.kicad_sch]
2026-06-30 MCU Power Pins Fix
    [MCU.kicad_sch, PC104_stack.kicad_sch, monarch_payload_interface_board_rev2.kicad_pcb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]
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2026-06-30 LED 12 VOLT Values / New Connector Footprints added
    [MCU.kicad_sch]
2026-07-01 Schematic Clean Up + New Micro-Lock Plus Connectors
    [MCU.kicad_sch, PC104_stack.kicad_sch, connectors.kicad_sch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]
2026-07-01 AD7124 Fixes
    [MCU.kicad_sch, PC104_stack.kicad_sch, connectors.kicad_sch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]
2026-07-01 Connector Footprints / Additions + Validated MAX31856
    [PC104_stack.kicad_sch, connectors.kicad_sch, pts.kicad_sch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]
2026-07-02 Connector FIX
    [connectors.kicad_sch]
2026-07-06 Schematic Updates Finished -> AD7124 Voltage Reading Fix + Connector Linkage Issue Fix
    [MCU.kicad_sch, PC104_stack.kicad_sch, connectors.kicad_sch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]
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2026-07-06 Initial Routing Work + Placement
    [MCU.kicad_sch, PC104_stack.kicad_sch, connectors.kicad_sch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]
2026-07-07 More layout routing (ad7124 pressure routing done)
    [monarch_payload_interface_board_rev2.kicad_pcb]
2026-07-07 Great progress almost done
    [MCU.kicad_sch, PC104_stack.kicad_sch, PIB STM32 Pinouts.xlsx]
2026-07-08 Layout Rev Done - NO DRC Check
    [PIB STM32 Pinouts.xlsx, monarch_payload_interface_board_rev2.kicad_pcb, monarch_payload_interface_board_rev2.kicad_sch]
2026-07-08 LED Board for Solenoid Valves
    [led_solenoid_valve_pcb.kicad_pcb, led_solenoid_valve_pcb.kicad_sch]
2026-07-08 PIB Rev Done -> Review Awaiting + DRC Check
    [monarch_payload_interface_board_rev2.kicad_pcb]
2026-07-08 DRC Fixes such as VIAs
    [monarch_payload_interface_board_rev2.kicad_pcb]
2026-07-08 FINAL REVIEW DONE + A lot of fixes. DRC PASSED
    [MCU.kicad_sch, PC104_stack.kicad_sch, connectors.kicad_sch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]
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2026-07-09 Schematic Unconnected Fix
    [MCU.kicad_sch, monarch_payload_interface_board_rev2.kicad_sch, thermocouples.kicad_sch]
2026-07-09 LED SOLENOID PCB Reviewed: ERC + DRC Pass
    [led_solenoid_valve_pcb.kicad_sch]
2026-07-09 Created Gerbers for PIB / LED Boards + Order Request
    [led_solenoid_valve_pcb-B_Cu.gbr, led_solenoid_valve_pcb-B_Mask.gbr, led_solenoid_valve_pcb-B_Paste.gbr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]
2026-07-14 Software Debugging Fun -> AD7124, MAX31856, FD2214
    [TEST2 Debug.cfg]
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2026-07-14 MAX31856 Driver Addition to Hardware Test -> Error Determination Functions
    [max31856.c]
2026-07-14 Hardware Testing Heater Added
    [monarch_payload_interface_board_rev1.csv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]
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2026-07-14 Integrated device ID code into main.c, new function for error determination, integrated singular and continous mode into program
    [ad7124_console_app.c, main.c]
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2026-07-14 FDC2214 Driver Reading Device/Manufacturing ID fix, added read/write abstraction functions, adding channel configuration functions and fixing entire driver based on arduino protocentral driver
    [ad7124.h, fdc2214.c, main.c]
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2026-07-22 MAX31856 fixes DRIVER WORKS!!!, AD7124 Fixes Driver does not work :(
    [ad7124_console_app.c, main.c, spi_support.c]
2026-07-23 FDC2214 Testing Driver Does Not Work - Comm Error
    [fdc2214.c, main.c]
2026-07-23 LED BLINK NOT WORKING
    [main.c]
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2026-07-24 AD7124 Driver Is cooked. Crashes the STM32
    [ad7124_console_app.c, fdc2214.c, main.c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]
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2026-07-24 Solenoid Valve not being actuated I think similar problem to led blink
    [main.c]
2026-07-25 Figured out why LED did not work... it was a hardware problem. IT'S FIXED!!
    [main.c]
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2026-07-31 NEW BREAKOUT BOARDS: Espray Plume Measurement Board + Capacitance Measurement Board + Accelerometer Board
    [5037630291.stp, 5037630491.stp, ADXL355BEZ.step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]
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2026-08-03 Ported Code over from Hardware test if this does not work means the porting over was bad
    [main.h, spi_support.c, spi_support.h]
2026-08-04 REV1 of plume measurement = test, REV2 = fit for flight box
    [CP-32-12_ADI.step, Plume_Measurment_Board.kicad_pcb, Plume_Measurment_Board.kicad_sch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]
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2026-08-05 Capacitance Board Schematic Done - Ran into issue with too big of BNC connectors
    [CM322522-180KL.SchLib, CM322522-180KL.stp, EDI2CAP.CFG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]
2026-08-06 Close Valve Cmds implementation + AD7124 + port over correct drivers
    [monarch_breakout_board_rev2.kicad_sch, untitled.kicad_sch]
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2026-08-06 Back Layer Noise Caps Placed
    [monarch_breakout_board_rev2.kicad_pcb]
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2026-08-06 Silkscreen Fixes
    [monarch_breakout_board_rev2.kicad_pcb]
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2026-08-06 Connector Fixes
    [Plume_Measurment_Board.kicad_sch, Voltage_Regulator.kicad_sch, untitled.kicad_sch]
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2026-08-12 New Schematic w/ Addition of two E-spray Amplification Signals
    [E-Spray_Plume_Measurement_1.kicad_sch, E-Spray_Plume_Measurement_2.kicad_sch, Plume_Measurment_Board.kicad_sch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]
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2026-08-13 Mech Drawing in User.Drawings + Progress Routing 5V regulator
    [Plume_Measurment_Board.kicad_pcb, untitled.kicad_sch]
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2026-08-13 Edge Cuts + Dimension Wor + Awaiting Dimension Approval
    [Plume_Measurment_Board.kicad_pcb]
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2026-08-16 ADDED COMMANDS such as valve readings + verfifed comptability with CLI
    [PLUME_MEASUREMENT_BOARD.step]
2026-08-18 Hardware Debug Software Changes + New Mounting Holes for the Plume Measurement Board
    [.stl, Plume_Measurement_Board_Mounting_Holes.step, Plume_Measurment_Board.kicad_pcb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]
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2026-08-28 HARDWARE TEST AD7124 Driver Replacement to fix multiple chip overwrite issue
    [ad7124_console_app.c, main.c]
2026-08-28 AD7124 fix in main flight software
    [ad7124.h, ad7124_console_app.c]
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2026-09-02 DRC Pass / Omitted A lot of Pointless Errors
    [Plume_Measurment_Board.kicad_pcb]
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2026-09-20 Removed Cold Junction Error Checking CLI Bug, Added Read Device ID functionality to CLI
    [main.c, main.py]
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2026-09-21 Fixed Header File linkeage issues eliminating the main.h file from driver files + Valve state + Temperature Update functions in sensors.h file
    [ad7124.h, main.h]
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2026-09-23 JSON Function Addition Need to build upon + Tested new threads they work however something wrong with update_voltage_data function which makes MCU crash
    [main.c, main.py, uart_handler.c]
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2026-09-29 GUI Work (Tabs Incorporated), AD7124 Driver Validated For all channels WORKS, and new resistor values for voltage divider added in kicad schematic
    [MCU.kicad_sch, PC104_stack.kicad_sch, connectors.kicad_sch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]
2026-09-30 Changed SPI1 Data Rate + Changed AD7124 driver to log voltage and current data at a software efficient manner (does not crash software any more! + Voltage & Current Poll CMDS now rely on the backgrou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
    [PIB_SOFTWARE.ioc, ad7124_console_app.c, main.c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]
2026-09-30 added voltage divider conversion formula + added more json data + fixed the reference payload_sys struct
    [uart_handler.c]
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2026-10-03 No longer killing thread
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2026-10-09 Ground GUI inspo + import + ad7177 driver channel config fix
    [fdc2214.c, main.c, main.py]
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

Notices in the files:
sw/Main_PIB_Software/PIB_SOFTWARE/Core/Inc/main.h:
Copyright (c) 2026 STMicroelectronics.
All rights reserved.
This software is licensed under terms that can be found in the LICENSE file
